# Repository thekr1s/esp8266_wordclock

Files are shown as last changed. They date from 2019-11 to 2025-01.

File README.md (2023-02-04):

# Get started on ubuntu 18.04 upto 20.04 (64 bits)
```
git clone https://github.com/thekr1s/esp8266_wordclock.git
cd esp8266_wordclock/esp-open-rtos
# NOTE Bearssl is outdated, and doesn't support CAfile, therefor disable check
git config --global http.sslverify false
git submodule update --init --recursive
cd ..
tar -xvf esp-open-sdk.tgz 
sudo apt-get install make gcc g++
sudo pip install esptool
. env.sh
cd wordclock
make
```

# Program ESP
## Windows
- Install ESP8266Flasher : https://github.com/nodemcu/nodemcu-flasher
- Install the driver for the USB2Sereial http://www.wch.cn/download/CH341SER_ZIP.html

Start the ESP8266Flasher.exe en vul het onderstaande in:

- esp8266_wordclock\esp-open-rtos\bootloader\firmware_prebuilt\rboot.bin            @ 0x00000
- esp8266_wordclock\esp-open-rtos\bootloader\firmware_prebuilt\blank_config.bin     @ 0x01000
- esp8266_wordclock\wordclock\firmware\ws2812_buffer.bin                            @ 0x02000

## Linux
After building the firmware with 'make' as discribed above, type the folliwing command:
```
make do_flash
```

# Setup Wordclock
- hierbenik: the request is build by: sprintf(buf, "GET %s HTTP/1.1\r\nHost: %s\r\nConnection:keep-alive\r\nAccept: */*\r\n\r\n", request, url);
- hierbenik request: "/get_with_age.php

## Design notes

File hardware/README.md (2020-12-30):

# Parts
## Electronics:
- NodeMcu Lolin V3 ESP32 [Link](https://www.ebay.com/itm/NodeMCU-V3-ESP8266-ESP-12-E-Lua-CH340-WiFI-WLan-IoT-Lolin-Mini-N3A2-V9T3/312753940110)
- Led strip: WS2812B [Link](https://www.ebay.com/itm/1-5m-WS2812B-RGB-Led-Strip-Light-30-60-144Leds-m-Individual-Addressable-IC-DC5V/401755047203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)
- LDR: 5MM GL5537 [Link](https://www.ebay.com/itm/20pcs-Photoresistor-5MM-GL5537-LDR-Photo-Resistors-Light-Dependent-Resistor/381374819080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)
- 100kOhm Resistor [link](https://www.ebay.com/itm/100PCS-1-4W-0-25W-Metal-Film-Resistor-1-Full-Range-of-Values-0-to-10M/252838503547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) 
- flat cable
- Power wire
- micro USB
- USB A
## Shop / Bouwmarkt:
- For frames clock:
    - Ikea RIBBA frame 23cm [link](https://www.ikea.com/nl/nl/p/ribba-fotolijst-zwart-40378401/)
    - Ikea RIBBA frame 50cm [link](https://www.ikea.com/nl/nl/p/ribba-fotolijst-zwart-00378436/)
- Multiplex timmerplaat gegrond 3 mm 122x61
- MDF 122x61cm 12/15mm
- Hoekprofiel aluminium 12x12/15x15 mm 2 meter
- Bison 2-componentenlijm kombi metaal 24 ml
- Plaatschroef 3x13 mm cilinderkop
## Special:
- letterplate
    - laser cutting: €50.0/€150.0
- led-divider cnc: (time)

# Electronic Wiring
- ESP(Rx) -> Led Strip (Data)
- ESP(GND) -> Led Strip (GND)
- ESP(VU) -> Led Strip (5v)
- LDR(1) -> ESP(GND)
- LDR(2) -> ESP(A0)
- ESP(A0) -> RESISTOR(100kOhm) -> ESP(3v)

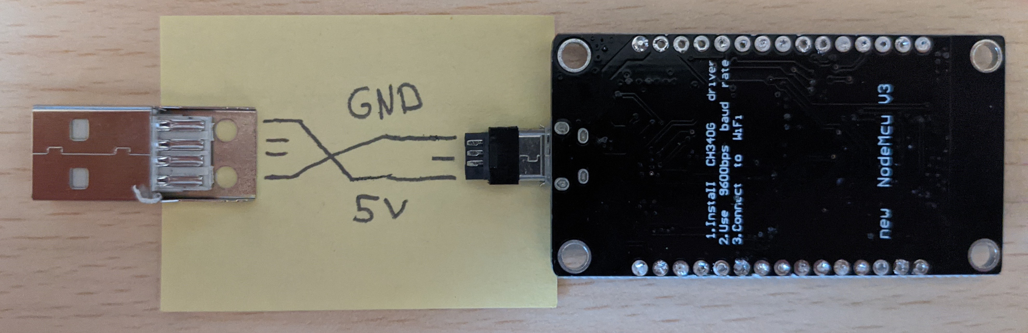
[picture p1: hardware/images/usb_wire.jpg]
- 

# Build Types
The wordclock can be created in 2 sizes because of the used led strip. Its 60 LED's per meter or 30 LED's per meter.
## Normal (Desk size)
- 60 Leds per meter
    - 11x11 letters => 121 LED's => (2.01m) => 3 meter ledstrip
- 12mm MDF plate 23*23 cm
- Hardboard 23*23 cm
### Frame (ikea RIBBA) 
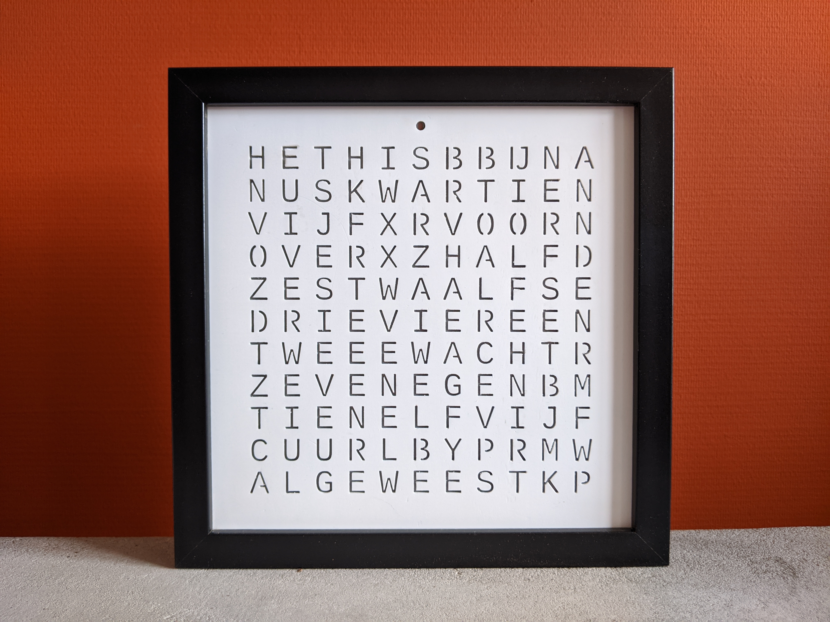
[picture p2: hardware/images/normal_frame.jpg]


### Frameless
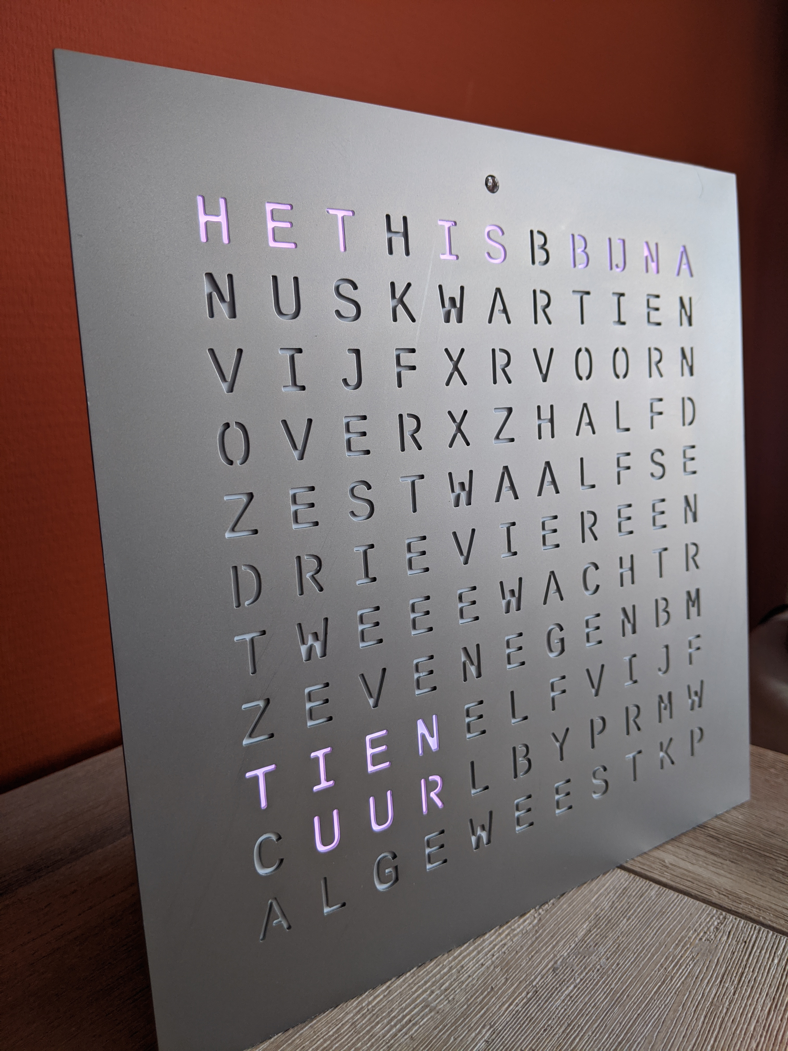
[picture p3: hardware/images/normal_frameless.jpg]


## Big clock (wall size)
The Big clock can be created with 11x11 letters or 13x13 letters
- 30 Leds per meter
    - 11x11 letters => 121 LED's => (4.04m) => 5 meter ledstrip
    - 13x13 letters => 169 LED's => (5.7m) => 6 meter ledstrip
- MDF plate 50*50 cm
- Hardboard 50*50 cm

### Frame 11x11 letters


### Frame 13x13 letters
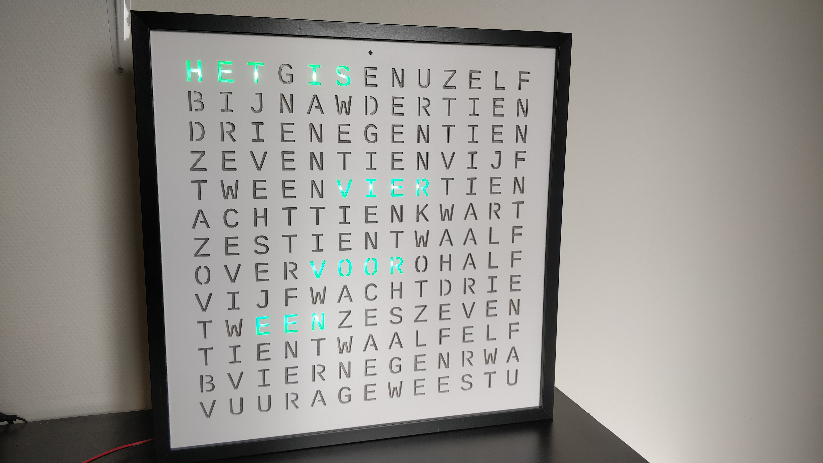
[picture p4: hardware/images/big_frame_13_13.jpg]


### Frameless 13x13 letters
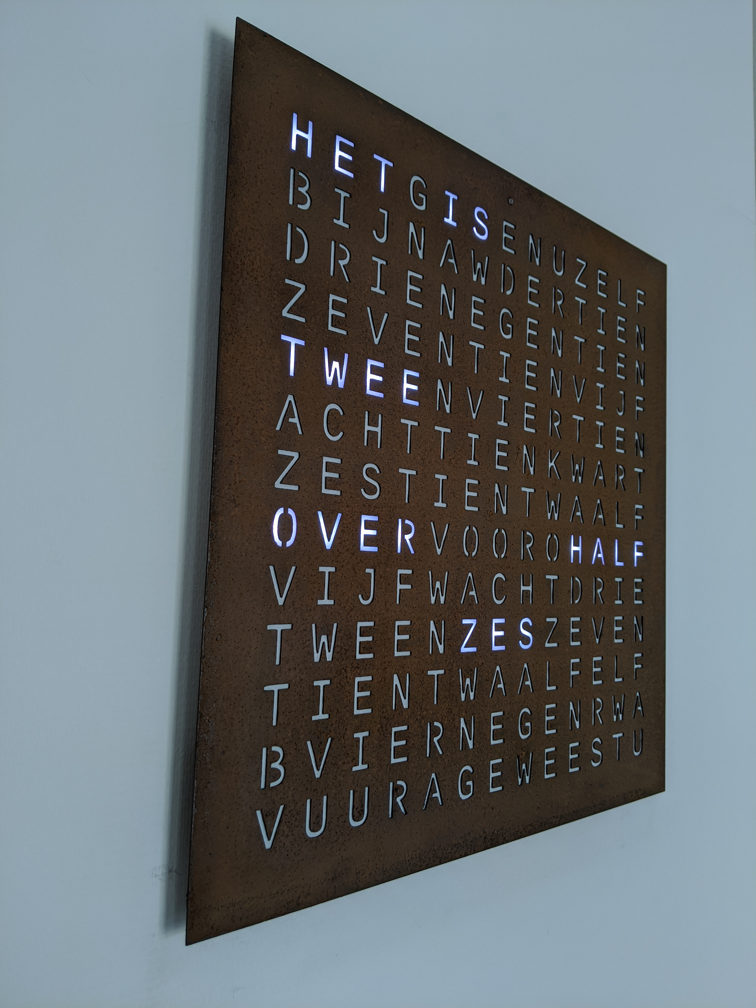
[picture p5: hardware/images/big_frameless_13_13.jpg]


# Assemble
The assembly can be divided into the following parts:
- led-panel
- light-divider
- letterplate
- Electronics
## light-divider
### CNC light-divider
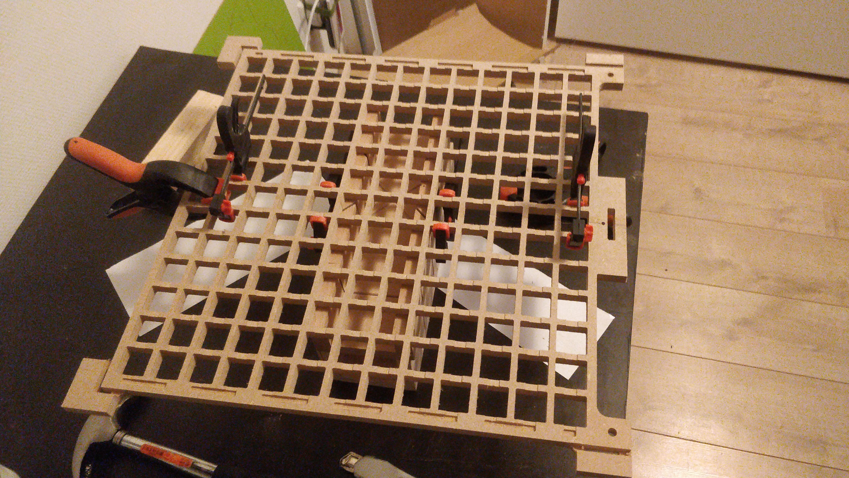
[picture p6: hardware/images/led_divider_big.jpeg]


### light-divider by hand
For the famed Clock the MDF plate need's to be 23x23 or 50x50 cm. For the frameless the MDF plate can be LxB 21x20 or 45,5x47 but start with 23x23 or 50x50.
The Normal clock can be made with 9mm or 12mm MDF plate.
The big clock can be made with 12mm or 15mm MDF plate.
- Determine the center of the plate by drawing 2 lines
- From the center draw a grid of lines
    - For the 60 led's per meter -> distance between lines is 1.6666 cm
    - For the 30 led's per meter -> distance between lines is 3.3333 cm
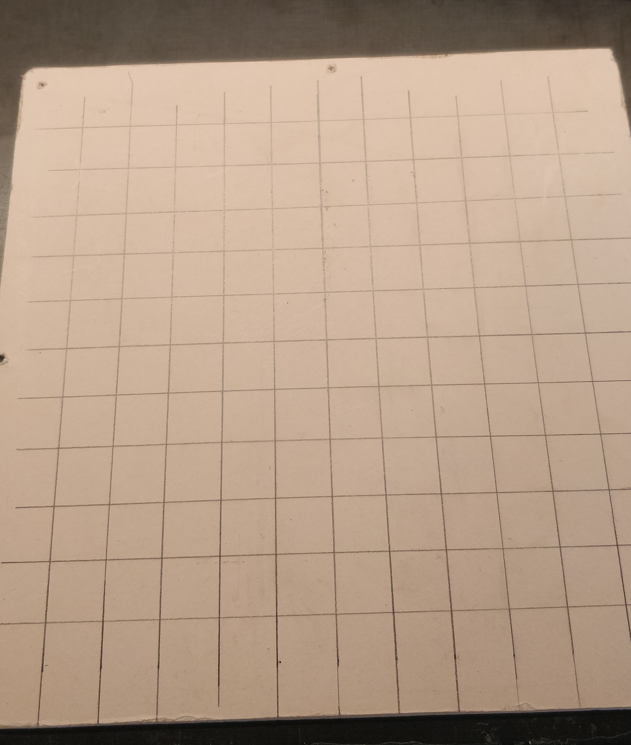
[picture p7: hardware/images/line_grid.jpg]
- 
- Drill a hole through each line crossing
    - Use a speed drill or a countersink bit
    - For the normal clock the hole is 12mm
    - For the big clock the hole is 30mm
- For the frameless clock the bottom, right and left side can be shorted so the letterplate will floating from the wall ~15mm(aluminium strip width) + 2mm spare
    - The top side is used to hang the clock
- The result should look like the cnc light-divider

## led-panel
- Place the led-panel under the light-divider.
- Trace the first, middle and last holes from the light-divider on the led panel
- Trace the outer line from the light-divider
    - in case of the frameless the top can be shorten 2 cm
- Cut peace’s from the ledstrip, (cut on the line that is drawn on the 3 copper paths)
    - For the 11x11 clock the ledstrip should be 11 leds long 
    - For the 13x13 clock the ledstrip should be 13 leds long 
- Place the led-strips with the led centred on the traces on the hardboard by following the this pattern:
    - Start upper left with Din and place it to the upper Right side end with Dout
    - The second row start with Dout on the left side and ends with Din
    - continue this zigzag pattern until all rows are done
- Use a Flat cable to connect the ledstrips from Dout to Din.
    - Cut flat cable, strip and tin both ends, cut the both ends so they are separated from each other
    - pre-solder both ends of the ledstrip
    - Start upper right with Dout solder all 3 pins(GND, Dout, 5V) Fold the flat cable 90 degrees down, fold it 90 degrees towards Din Solder again
- drill a hole next to the first led, and next to the last led
- Connect power supply from the first led to the last led with the red/black wire
- Connect the powers supply and the Din with the ESP (see Electronic Wiring)
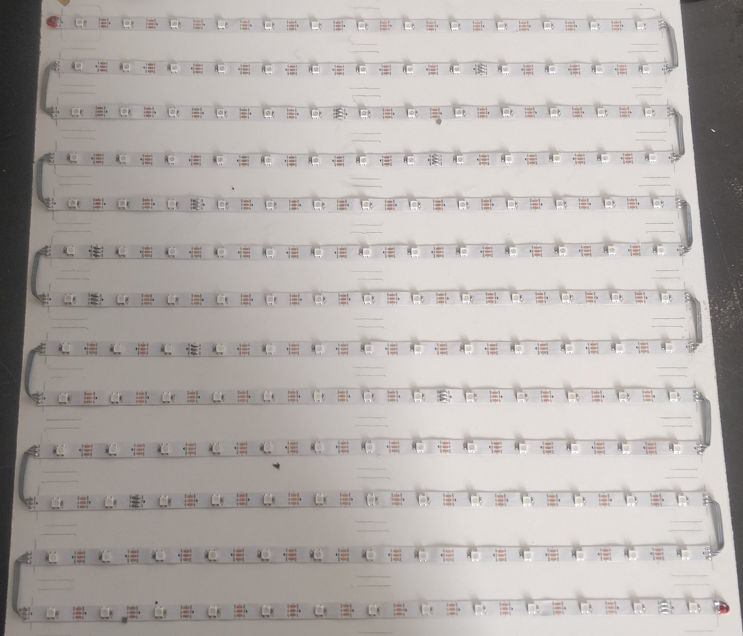
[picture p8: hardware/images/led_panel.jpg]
- 
- You should be able to test the LED panel by connection the ESP to its power supply

## Connect the led-panel with the light-divider
- Place the light-divider on the led-panel and make sure all leds are centred
- Drill (1.5mm) hole through both panels. These hols can later be used to connect both panels
- Flip it and screw both panels to each other.
- Frameless ESP placement
    - Big clock place the ESP in the upper right corner (hot glue)
    - Normal clock the ESP will be screwed to the back
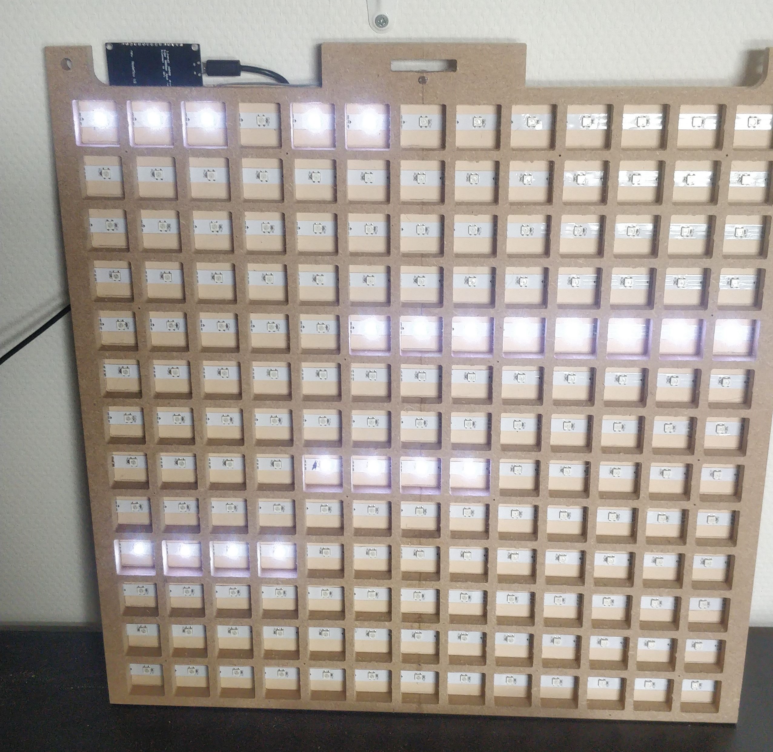
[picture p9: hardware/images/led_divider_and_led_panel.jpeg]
- 

## Diffuser (to be improved)
- place the paper over the light-divider and cut it on size
- make sure its stays in place with tape

## Letterplate
### frame
- Connect the LDR and the resistor (see Electronic Wiring)
- fix the ESP with a screw to the back of the led-panel
- Place the letterplate and the light divider in the frame
- place some foam in the back so all is pushed forwarded
- Close the frame
### frameless
- Center the light-divider on the letterplate and drill the LDR hole
- Draw the outer line from the light-divider on theletterplates back
- Cut the aluminium strip so it fits nicely around the light-divider (left, right and bottom)
- Make both the letterplate and the aluminium strip rough with sanding paper
- drill 3 holes in all aluminium strips (used for connecting the letterplate to the light-divider)
- glue the aluminium strip on the letterplate (use glue clamps) wait 24 hours
- screw the letterplate to the light-divider
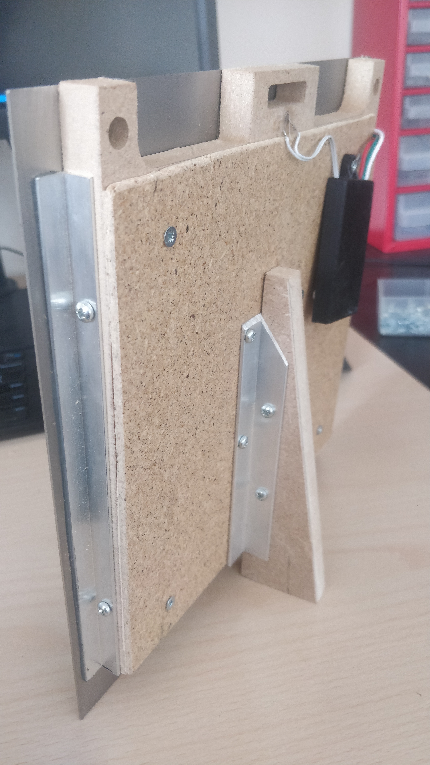
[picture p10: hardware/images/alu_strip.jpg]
- 

# Hardware Drawings
## letterplate
- I Have created a FreeCAD pyhton macro for generating a Letterplate, ..\hardware\lettering_plates\FreeCAD_drawings\freecad_macro
- The letterplate is parametric so can be used for 11*11 of 13*13
- After the generation is done, export the part as .STEP (the DXF generator from freecad is not smooth)
- FreeCAD export DXF WORKS (0.18.4):
    - Edit -> Preference -> Inport-Export -> DXF
    - Max Spline Segment to 0,1 or 0,01 mm (NOTE use , instead of .)
    - Select all elements
    - File -> Export -> Autodesk DXF 2d
- Import the .STEP file into Fusion for creating the DXF file of gcode
- G-code
    - Create A body by setting the Hight
    - Switch to manufacture
    - start creating the Gcode
- DXF:
    - Create a sketch on the Top view
    - Menu -> Create -> Project / include -> include 3D Geometry
    - Select the Body from the letterplate
    - Save Sketch -> right klik the Sketch and save as DXF
## ledschotten
- The LDR for the 11*11 clock is 214.444 mm from the bottom (This information is printed by FreeCAD)
- The LDR for the 13*13 clock is 477.778 mm from the bottom
- The LEDschotten is completely drawn in Fusion360, and is partly parametric.

# Tips & tricks:
- The MDF plate can also be replaced by "Foamed pvc"

# Note:
The NodeMcu Lolin V3 is needed because the Lolin has a 3v reference voltage for its adc that is used for the LDR all other NodeMC have 1v reference voltage

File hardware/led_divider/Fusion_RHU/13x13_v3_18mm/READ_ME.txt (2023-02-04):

#Init homing 
G92 x0 y0 z0
f10000
x5 y30
G92 x0 y0 z0
#plase the inital tool 2mm?
M6

#Jog to Z0 (top of wood)
G92 Z0
Z20

The flip pins fixure is:
240*550mm
Starts on X5 Y30

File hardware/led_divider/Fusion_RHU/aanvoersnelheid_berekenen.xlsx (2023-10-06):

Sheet: Blad1
Aanvoersnelheid = (aanvoer x 1000) : (toerental x aantal tanden)

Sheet: Materiaal Fz
https://www.stepcraft-systems.com/en/services/milling-parameters
 | End Mill Diamater
ø Cutting Speed | ø 1 mm | ø 2 mm | ø 3 mm | ø 4 mm | ø 5 mm | ø 6 mm | ø 8 mm | ø 10 mm | ø 12 mm
m/min.* | Feed Rate in mm / Tooth / Revolution
Cast Aluminum > 6 % Si | 200 | 0.01 | 0.01 | 0.01 | 0.015 | 0.015 | 0.025 | 0.03 | 0.038 | 0.05
Wrought Aluminum Alloy | 500 | 0.01 | 0.02 | 0.025 | 0.05 | 0.05 | 0.05 | 0.064 | 0.08 | 0.1
Soft Plastic | 600 | 0.025 | 0.03 | 0.035 | 0.045 | 0.065 | 0.09 | 0.1 | 0.2 | 0.3
Hard Plastic | 550 | 0.015 | 0.02 | 0.025 | 0.05 | 0.06 | 0.08 | 0.089 | 0.1 | 0.15
Hard Wood | 450 | 0.02 | 0.025 | 0.03 | 0.055 | 0.065 | 0.085 | 0.095 | 0.095 | 0.155
Soft Wood | 500 | 0.025 | 0.03 | 0.035 | 0.06 | 0.07 | 0.09 | 0.1 | 0.11 | 0.16
MDF | 450 | 0.05 | 0.07 | 0.1 | 0.15 | 0.2 | 0.3 | 0.4 | 0.5 | 0.6
Brass, Copper, Bronze | 365 | 0.015 | 0.02 | 0.025 | 0.025 | 0.03 | 0.05 | 0.056 | 0.065 | 0.08
Steel | 75 | 0.01 | 0.01 | 0.012 | 0.025 | 0.03 | 0.038 | 0.045 | 0.05 | 0.08

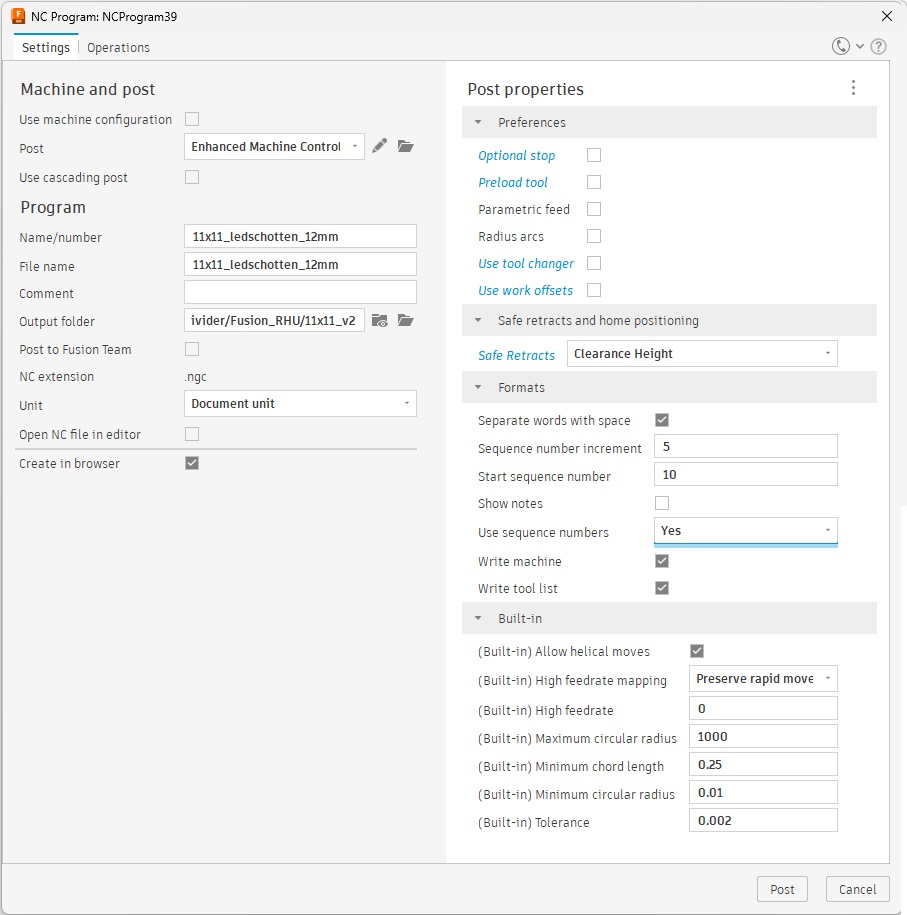
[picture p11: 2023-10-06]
hardware/led_divider/Fusion_RHU/FUSION_SETTINGS_POST_PROCESS.jpg

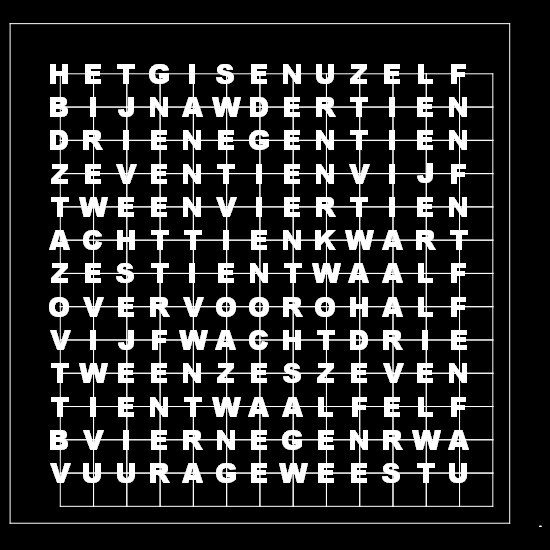
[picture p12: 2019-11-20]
hardware/lettering_plates/QCAD_letterplaat/WOORDCLOCK_2.bmp

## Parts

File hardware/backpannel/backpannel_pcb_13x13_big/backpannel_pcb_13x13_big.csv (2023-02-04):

Source: | Y:\home\rutger\proj\esp8266_wordclock\hardware\backpannel\backpannel_pcb_13x13_big\backpannel_pcb_13x13_big.kicad_sch
Date: | 29/12/2022 17:19:29
Tool: | Eeschema (6.0.0)
Generator: | C:\Program Files\KiCad\6.0\bin\scripting\plugins/bom_csv_grouped_by_value.py
Component Count: | 32
Individual Components:
Item | Qty | Reference(s) | Value | LibPart | Footprint | Datasheet
 |  | C1 | 10uF | Device:C | Capacitor_SMD:C_0805_2012Metric_Pad1.18x1.45mm_HandSolder | ~
 |  | C2 | 10uF | Device:CP | Capacitor_SMD:CP_Elec_6.3x5.4
 |  | C3 | 10uF | Device:C | Capacitor_SMD:C_0805_2012Metric_Pad1.18x1.45mm_HandSolder | ~
 |  | D1 | D_Schottky | Device:D_Schottky | Diode_SMD:D_0805_2012Metric_Pad1.15x1.40mm_HandSolder | ~
 |  | J1 | Conn_02x03 | Connector_Generic:Conn_02x03_Odd_Even | Connector_PinHeader_2.54mm:PinHeader_2x03_P2.54mm_Vertical | ~
 |  | J2 | Conn_01x02_Female | Connector:Conn_01x03_Female | Connector_BarrelJack:BarrelJack_CLIFF_FC681465S_SMT_Horizontal | ~
 |  | JP1 | ledstrip | Jumper:SolderJumper_2_Open | Jumper:SolderJumper-2_P1.3mm_Open_RoundedPad1.0x1.5mm | ~
 |  | R1 | 100k | Device:R | Resistor_SMD:R_0805_2012Metric_Pad1.20x1.40mm_HandSolder | ~
 |  | R2 | LDR | Sensor_Optical:LDR03 | OptoDevice:R_LDR_5.1x4.3mm_P3.4mm_Vertical | http://www.elektronica-componenten.nl/WebRoot/StoreNL/Shops/61422969/54F1/BA0C/C664/31B9/2173/C0A8/2AB9/2AEF/LDR03IMP.pdf
 |  | R3 | 100k | Device:R | Resistor_SMD:R_0805_2012Metric_Pad1.20x1.40mm_HandSolder | ~
 |  | R4 | 220k | Device:R | Resistor_SMD:R_0805_2012Metric_Pad1.20x1.40mm_HandSolder | ~
 |  | R5 | 12k | Device:R | Resistor_SMD:R_0805_2012Metric_Pad1.20x1.40mm_HandSolder | ~
 |  | R6 | 12k | Device:R | Resistor_SMD:R_0805_2012Metric_Pad1.20x1.40mm_HandSolder | ~
 |  | R7 | 12k | Device:R | Resistor_SMD:R_0805_2012Metric_Pad1.20x1.40mm_HandSolder | ~
 |  | R8 | 12k | Device:R | Resistor_SMD:R_0805_2012Metric_Pad1.20x1.40mm_HandSolder | ~
 |  | R9 | 12k | Device:R | Resistor_SMD:R_0805_2012Metric_Pad1.20x1.40mm_HandSolder | ~
 |  | R10 | 330 | Device:R | Resistor_SMD:R_0805_2012Metric_Pad1.20x1.40mm_HandSolder | ~
 |  | S1 | WS2812_ledstrip | woordklok_symbol:WS2812_ledstrip | woordklok_footprint:WS2812_ledstrip_30leds_meter
 |  | S2 | WS2812_ledstrip | woordklok_symbol:WS2812_ledstrip | woordklok_footprint:WS2812_ledstrip_30leds_meter
 |  | S3 | WS2812_ledstrip | woordklok_symbol:WS2812_ledstrip | woordklok_footprint:WS2812_ledstrip_30leds_meter
 |  | S4 | WS2812_ledstrip | woordklok_symbol:WS2812_ledstrip | woordklok_footprint:WS2812_ledstrip_30leds_meter
 |  | S5 | WS2812_ledstrip | woordklok_symbol:WS2812_ledstrip | woordklok_footprint:WS2812_ledstrip_30leds_meter
 |  | S6 | WS2812_ledstrip | woordklok_symbol:WS2812_ledstrip | woordklok_footprint:WS2812_ledstrip_30leds_meter
 |  | S7 | WS2812_ledstrip | woordklok_symbol:WS2812_ledstrip | woordklok_footprint:WS2812_ledstrip_30leds_meter
 |  | S8 | WS2812_ledstrip | woordklok_symbol:WS2812_ledstrip | woordklok_footprint:WS2812_ledstrip_30leds_meter
 |  | S9 | WS2812_ledstrip | woordklok_symbol:WS2812_ledstrip | woordklok_footprint:WS2812_ledstrip_30leds_meter
 |  | S10 | WS2812_ledstrip | woordklok_symbol:WS2812_ledstrip | woordklok_footprint:WS2812_ledstrip_30leds_meter
 |  | S11 | WS2812_ledstrip | woordklok_symbol:WS2812_ledstrip | woordklok_footprint:WS2812_ledstrip_30leds_meter
 |  | S12 | WS2812_ledstrip | woordklok_symbol:WS2812_ledstrip | woordklok_footprint:WS2812_ledstrip_30leds_meter
 |  | S13 | WS2812_ledstrip | woordklok_symbol:WS2812_ledstrip | woordklok_footprint:WS2812_ledstrip_30leds_meter
 |  | U1 | AMS1117-3.3 | Regulator_Linear:AMS1117-3.3 | Package_TO_SOT_SMD:SOT-223-3_TabPin2 | http://www.advanced-monolithic.com/pdf/ds1117.pdf
 |  | U2 | ESP-12E | RF_Module:ESP-12E | RF_Module:ESP-12E | http://wiki.ai-thinker.com/_media/esp8266/esp8266_series_modules_user_manual_v1.1.pdf
Collated Components:
Item | Qty | Reference(s) | Value | LibPart | Footprint | Datasheet
1 | 2 | C1, C3 | 10uF | Device:C | Capacitor_SMD:C_0805_2012Metric_Pad1.18x1.45mm_HandSolder | ~
2 | 1 | C2 | 10uF | Device:CP | Capacitor_SMD:CP_Elec_6.3x5.4
3 | 1 | D1 | D_Schottky | Device:D_Schottky | Diode_SMD:D_0805_2012Metric_Pad1.15x1.40mm_HandSolder | ~
4 | 1 | J1 | Conn_02x03 | Connector_Generic:Conn_02x03_Odd_Even | Connector_PinHeader_2.54mm:PinHeader_2x03_P2.54mm_Vertical | ~
5 | 1 | J2 | Conn_01x02_Female | Connector:Conn_01x03_Female | Connector_BarrelJack:BarrelJack_CLIFF_FC681465S_SMT_Horizontal | ~
6 | 1 | JP1 | ledstrip | Jumper:SolderJumper_2_Open | Jumper:SolderJumper-2_P1.3mm_Open_RoundedPad1.0x1.5mm | ~
7 | 2 | R1, R3 | 100k | Device:R | Resistor_SMD:R_0805_2012Metric_Pad1.20x1.40mm_HandSolder | ~
8 | 1 | R2 | LDR | Sensor_Optical:LDR03 | OptoDevice:R_LDR_5.1x4.3mm_P3.4mm_Vertical | http://www.elektronica-componenten.nl/WebRoot/StoreNL/Shops/61422969/54F1/BA0C/C664/31B9/2173/C0A8/2AB9/2AEF/LDR03IMP.pdf
9 | 1 | R4 | 220k | Device:R | Resistor_SMD:R_0805_2012Metric_Pad1.20x1.40mm_HandSolder | ~
10 | 5 | R5, R6, R7, R8, R9 | 12k | Device:R | Resistor_SMD:R_0805_2012Metric_Pad1.20x1.40mm_HandSolder | ~
11 | 1 | R10 | 330 | Device:R | Resistor_SMD:R_0805_2012Metric_Pad1.20x1.40mm_HandSolder | ~
12 | 13 | S1, S2, S3, S4, S5, S6, S7, S8, S9, S10, S11, S12, S13 | WS2812_ledstrip | woordklok_symbol:WS2812_ledstrip | woordklok_footprint:WS2812_ledstrip_30leds_meter
13 | 1 | U1 | AMS1117-3.3 | Regulator_Linear:AMS1117-3.3 | Package_TO_SOT_SMD:SOT-223-3_TabPin2 | http://www.advanced-monolithic.com/pdf/ds1117.pdf
14 | 1 | U2 | ESP-12E | RF_Module:ESP-12E | RF_Module:ESP-12E | http://wiki.ai-thinker.com/_media/esp8266/esp8266_series_modules_user_manual_v1.1.pdf

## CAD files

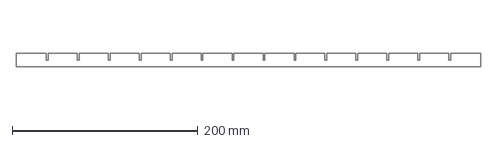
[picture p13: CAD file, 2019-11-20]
hardware/__attic/shotten/schotjes_layout_15mm.dxf
500.0 x 15.0 mm

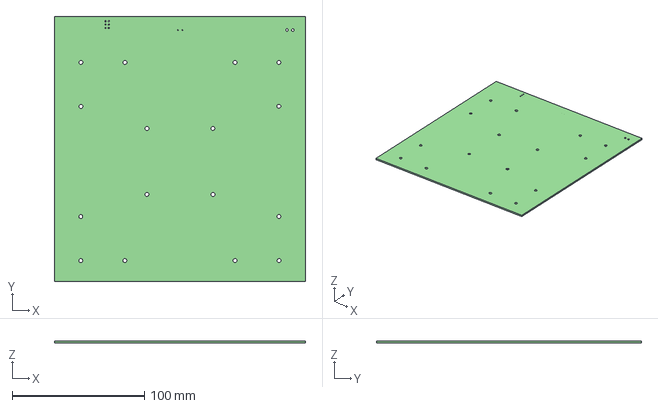
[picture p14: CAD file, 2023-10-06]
hardware/backpannel/backpannel_pcb_11x11_small/backpannel_pcb_11x11_small.step
190.0 x 200.6 x 1.60 mm

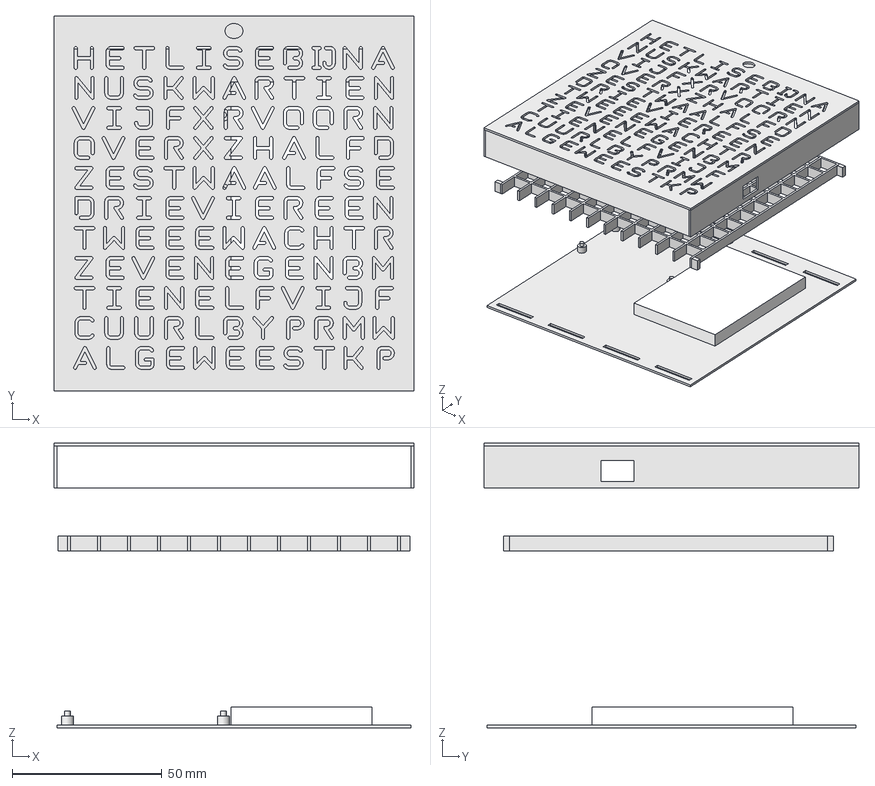
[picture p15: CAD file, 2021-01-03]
hardware/housing/120x120/housing.FCStd
120.0 x 125.0 x 95.0 mm
Letterplate
backsink

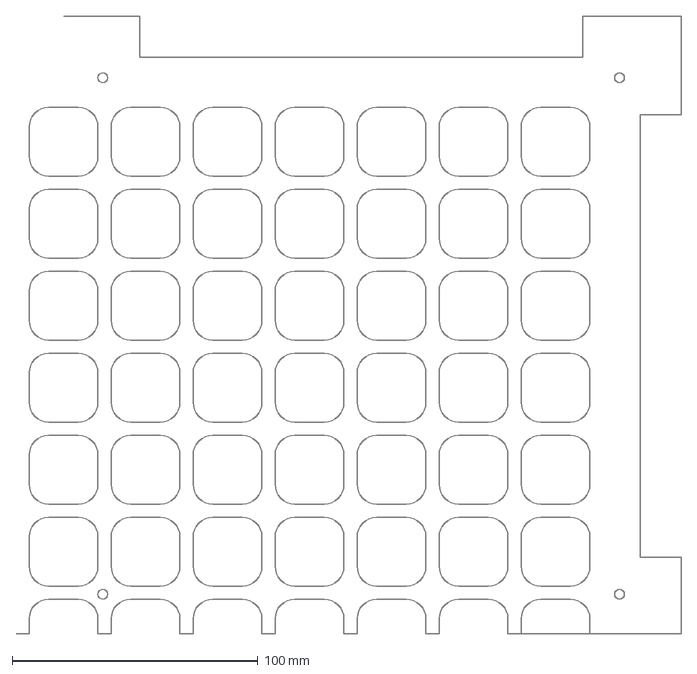
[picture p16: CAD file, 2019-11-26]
hardware/led_divider/cambam_RWA/gatenboard_groot_13x13_kwart.dxf
270.3 x 251.0 mm

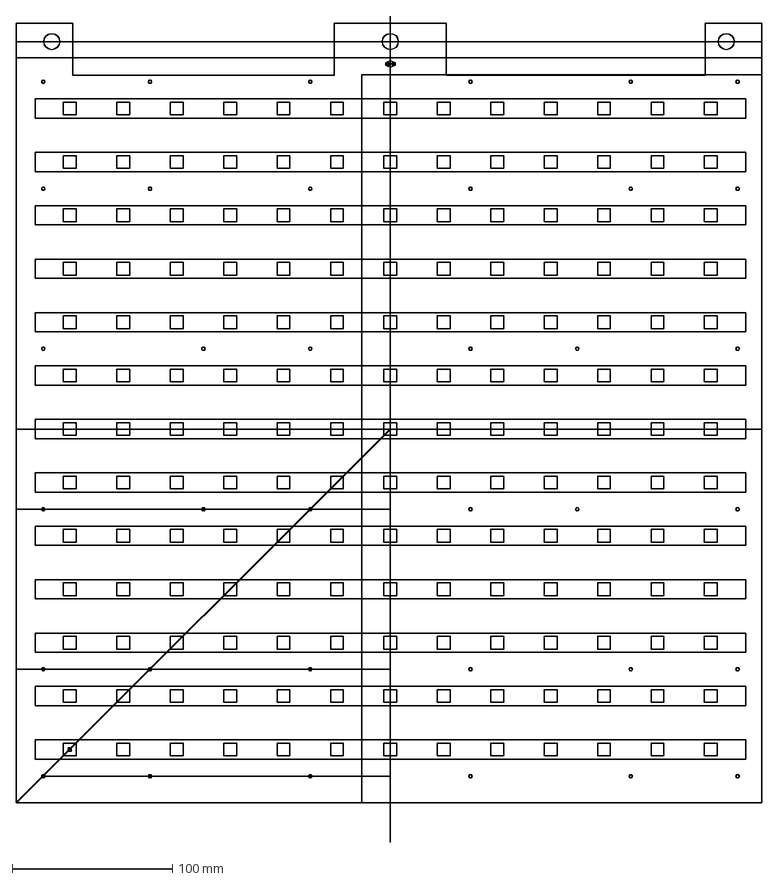
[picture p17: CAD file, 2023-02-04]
hardware/led_divider/Fusion_RHU/ledschotten_13_13_V2.dxf
465.0 x 515.4 mm

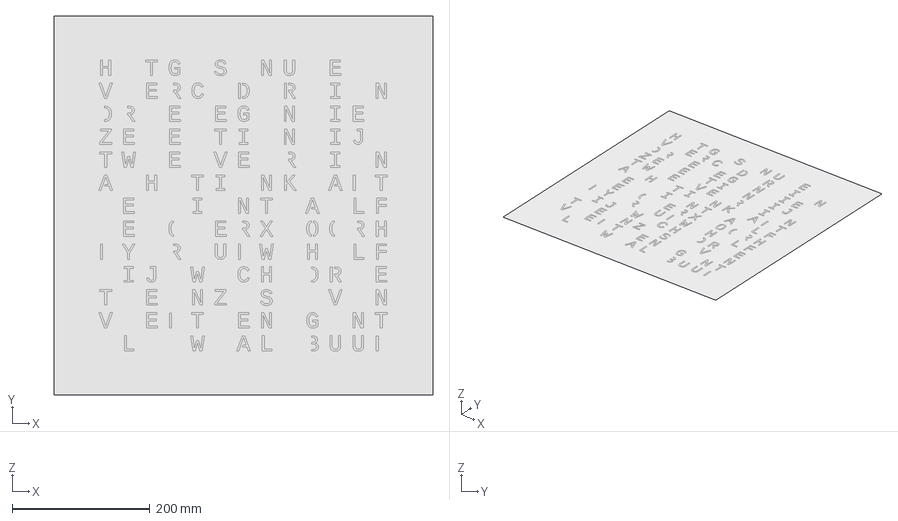
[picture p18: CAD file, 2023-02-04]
hardware/lettering_plates/FreeCAD_drawings/letterplate_13_13_V2_freecad.step
550.0 x 550.0 x 0 mm
Circle
ShapeString
ShapeString001
ShapeString002
ShapeString003
ShapeString004
ShapeString005
ShapeString006
ShapeString007
ShapeString008
ShapeString009
ShapeString010
ShapeString011
ShapeString012
ShapeString013
ShapeString014
ShapeString015
ShapeString016
ShapeString017
ShapeString018
ShapeString019
ShapeString020
ShapeString021
ShapeString022
ShapeString023
ShapeString024
ShapeString025
ShapeString026
ShapeString027
ShapeString028
ShapeString029
ShapeString030
ShapeString031
ShapeString032
ShapeString033
ShapeString034
ShapeString035
ShapeString036
ShapeString037
ShapeString038
ShapeString039
ShapeString040
ShapeString041
ShapeString042
ShapeString043
ShapeString044
ShapeString045
ShapeString046
ShapeString047
ShapeString048
ShapeString049
ShapeString050
ShapeString051
ShapeString052
ShapeString053
ShapeString054
ShapeString055
ShapeString056
ShapeString057
ShapeString058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

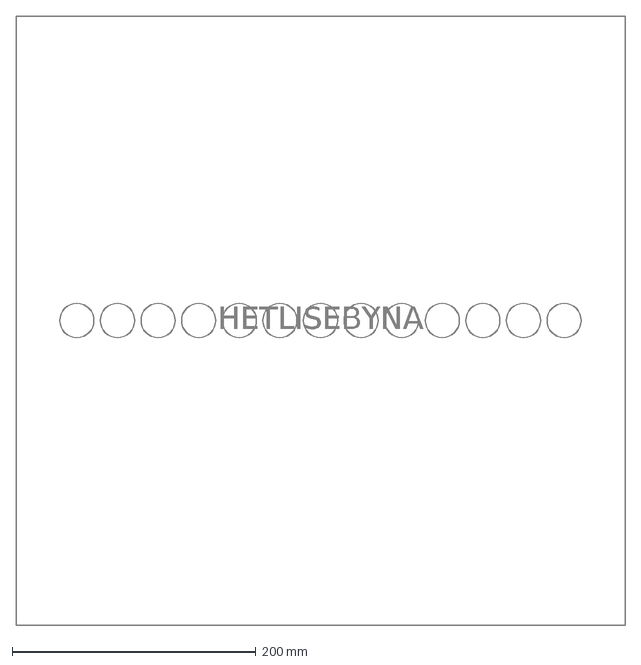
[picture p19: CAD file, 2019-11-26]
hardware/lettering_plates/letterplaat_rwa/letterplaat_groot.dxf
HETLISEBYNA

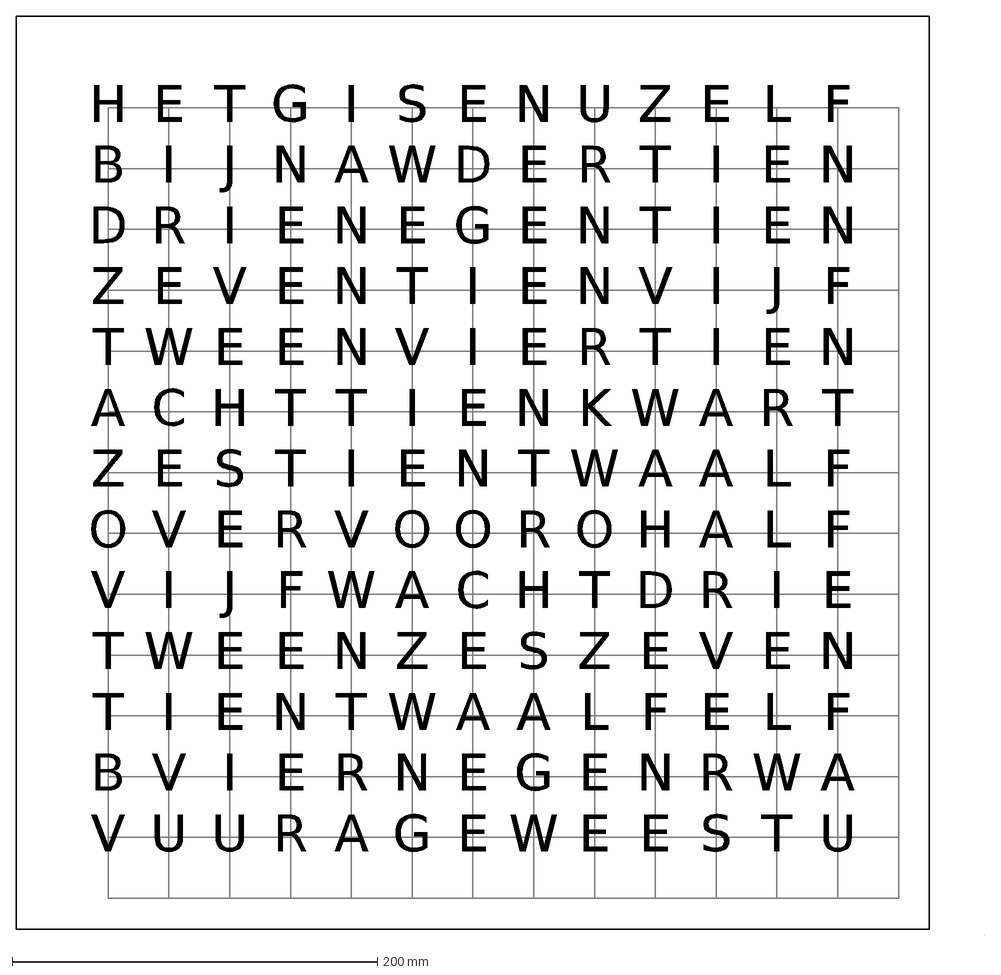
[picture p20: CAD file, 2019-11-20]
hardware/lettering_plates/QCAD_letterplaat/WOORDCLOCK_2.dxf
H
E
T
G
I
S
N
U
Z
L
F
W
D
A
R
B
J
V
K
C
O

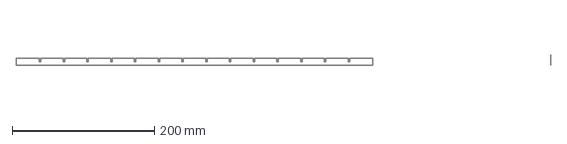
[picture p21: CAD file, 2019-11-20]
hardware/__attic/shotten/schotjes_layout.dxf
750.0 x 15.0 mm

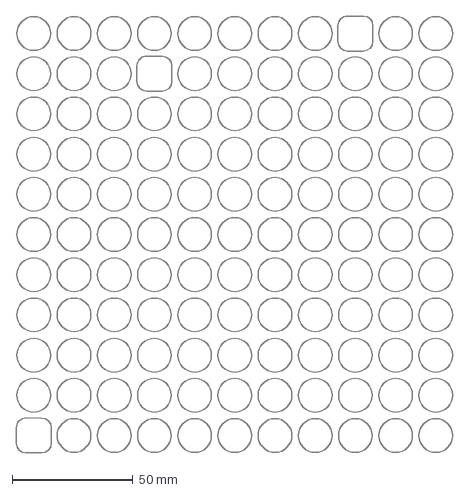
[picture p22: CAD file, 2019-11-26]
hardware/led_divider/cambam_RWA/gatenboard.dxf
180.9 x 181.2 mm

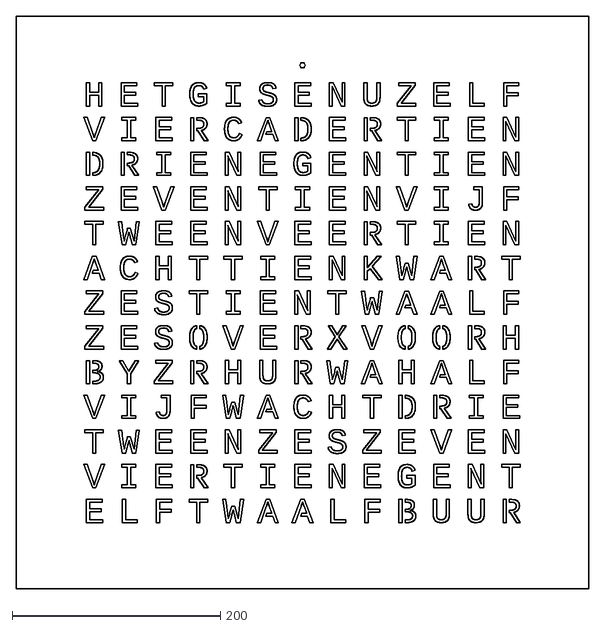
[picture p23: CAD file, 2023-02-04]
hardware/lettering_plates/FreeCAD_drawings/letterplate_13_13_V2_Qcad.dxf
550.0 x 550.0

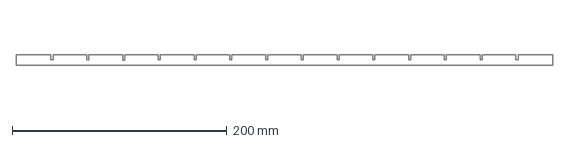
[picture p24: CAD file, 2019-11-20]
hardware/__attic/shotten/schotjes_layout_zonderMaten.dxf
500.0 x 10.0 mm

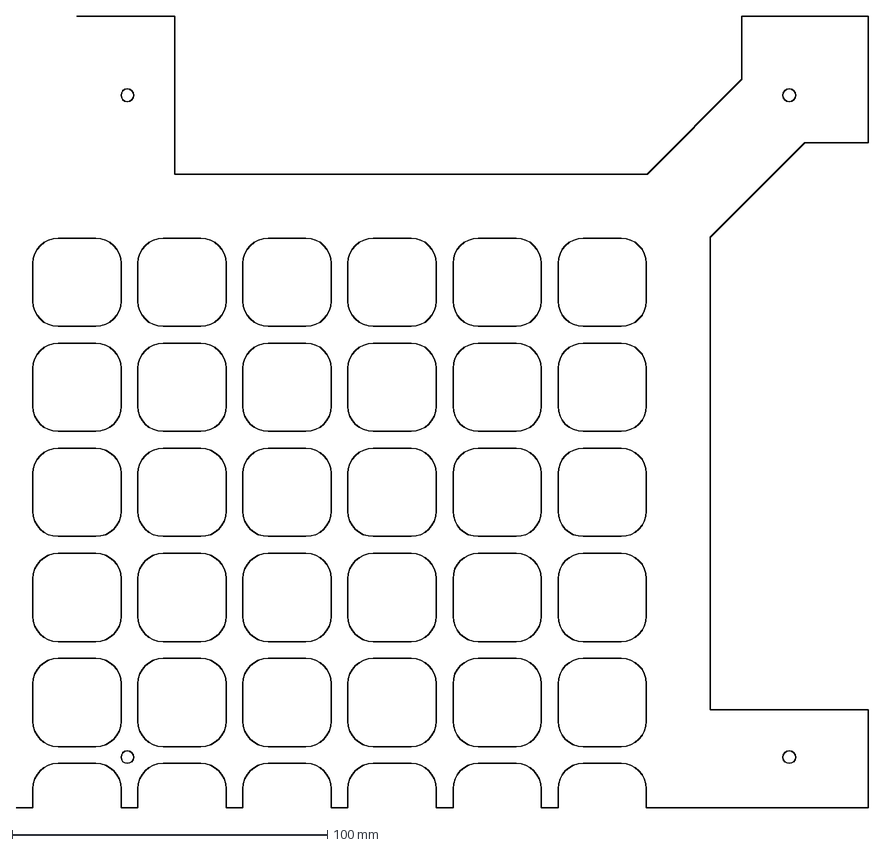
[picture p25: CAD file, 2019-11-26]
hardware/led_divider/cambam_RWA/gatenboard_groot_kwart.dxf
270.3 x 251.0 mm

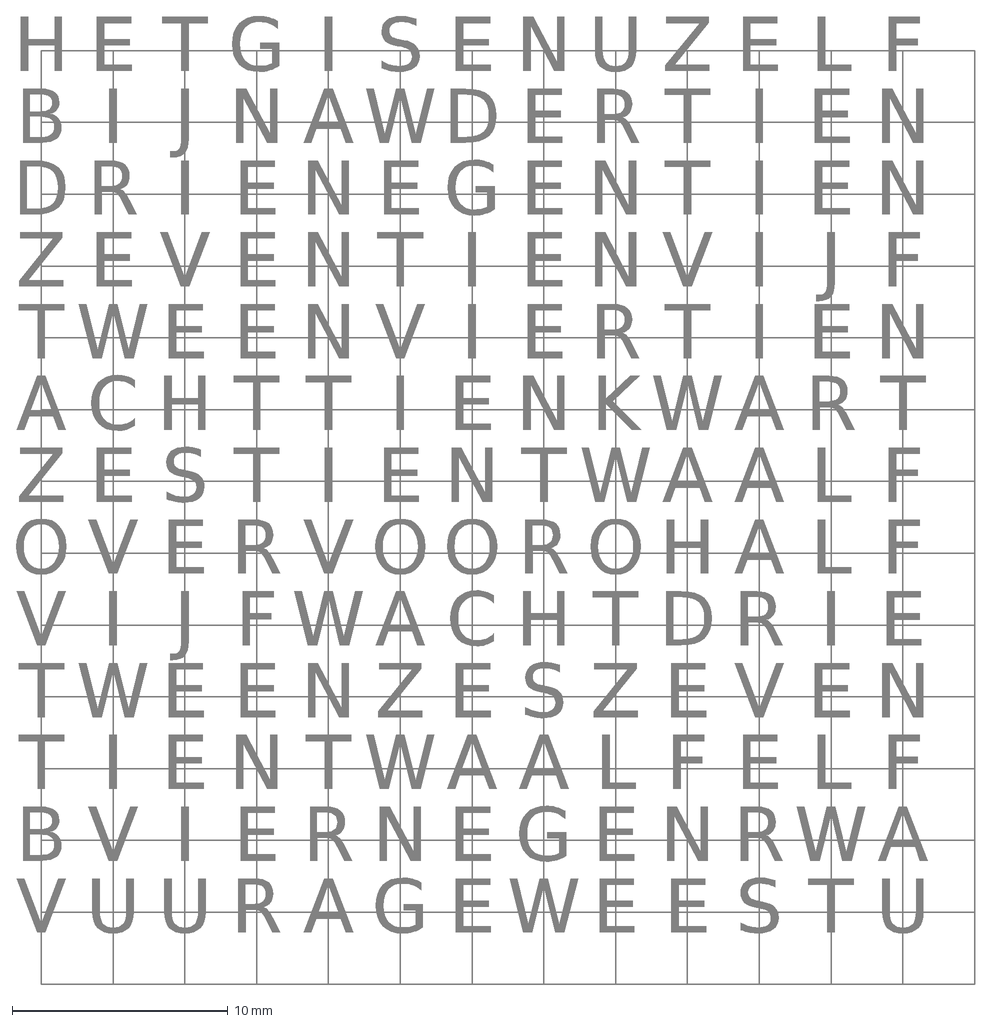
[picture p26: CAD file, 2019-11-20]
hardware/lettering_plates/QCAD_letterplaat/WOORDCLOCK.dxf
H
E
T
G
I
S
N
U
Z
L
F
W
D
A
R
B
J
V
K
C
O

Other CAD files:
hardware/lettering_plates/QCAD_letterplaat/WOORDCLOCK_3.dxf
hardware/led_divider/cambam_RWA/gatenboard_groot_13x13_half.dxf
hardware/lettering_plates/FreeCAD_drawings/letterplate_11_11_freecad.dxf
hardware/lettering_plates/QCAD_letterplaat/WOORDCLOCK_1.dxf
hardware/led_divider/Fusion_RHU/old/ledschotten_frameless_11_11 v29.stl
hardware/led_divider/Fusion_RHU/old/ledschotten_frameless_13_13 v14.stl
hardware/led_divider/Fusion_RHU/old/ledschotten_frameless_13_13 v16.stl
hardware/led_divider/Fusion_RHU/old/ledschotten_ikea_11_11 v9.dxf
hardware/led_divider/Fusion_RHU/old/ledschotten_ikea_11_11 v9.stl
hardware/led_divider/Fusion_RHU/old/ledschotten_ikea_13_13 v9.stl
hardware/lettering_plates/FreeCAD_drawings/letterplate_11_11.FCStd
hardware/lettering_plates/FreeCAD_drawings/letterplate_11_11_fusion360_v2.dxf
hardware/lettering_plates/FreeCAD_drawings/letterplate_13_13.FCStd
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

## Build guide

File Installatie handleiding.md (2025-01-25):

# Installatie handleiding
Deze handleiding zal stapsgewijs uitleggen hoe u de klok kunt installeren en gebruiken. Het laatste hoofdstuk zal veel gestelde vragen beantwoorden.
## Installatie 
De klok haalt zijn tijd op vanaf het internet, Dit kan de klok alleen doen zodra de klok verbind met uw WiFi thuis. Nadat de klok met uw WiFi is verbonden zal de klok altijd de goede tijd weergeven.
### Stap 1:
- Sluit de USB aan op een USB adapter van minimaal 1A, 
- Sluit de andere kant aan op de controller van de klok

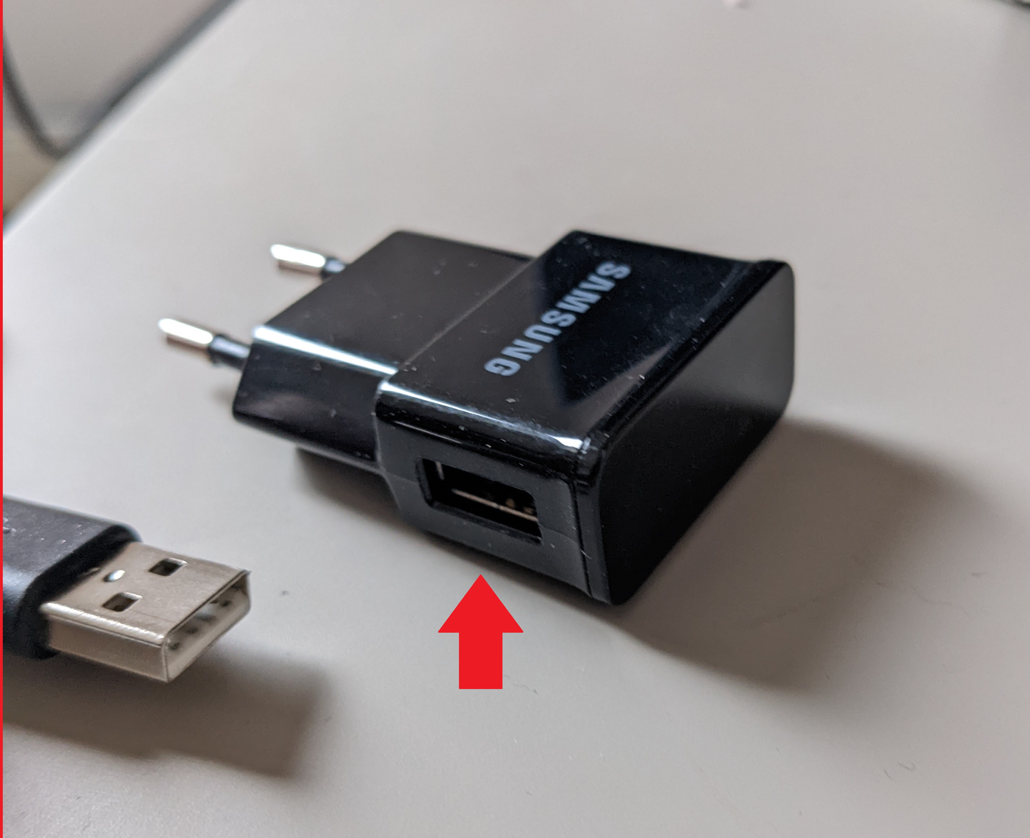
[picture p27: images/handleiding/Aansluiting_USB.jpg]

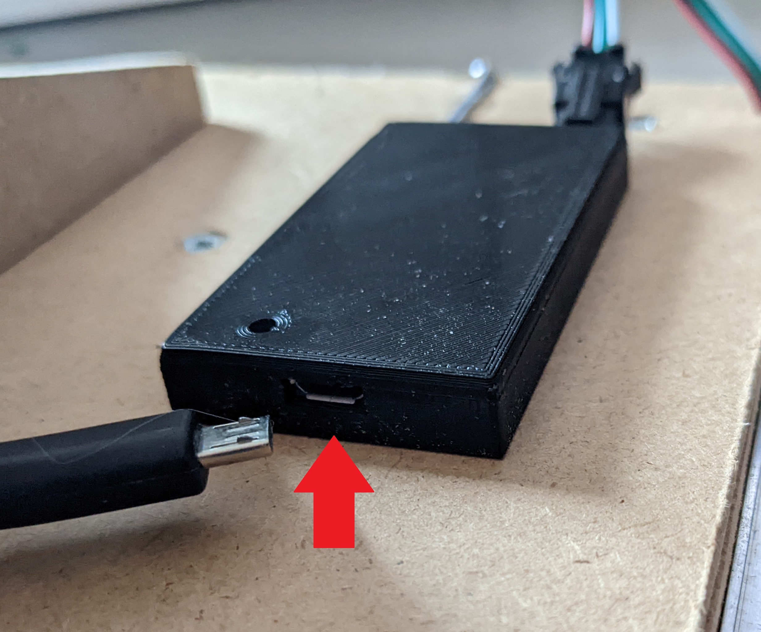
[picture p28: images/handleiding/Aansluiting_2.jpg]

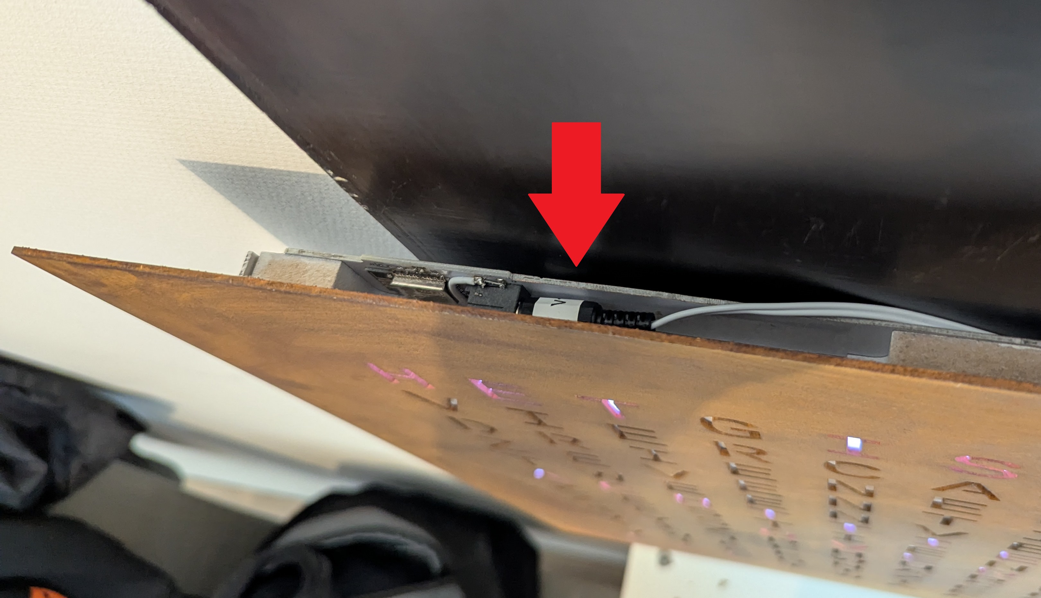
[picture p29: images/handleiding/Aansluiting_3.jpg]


- Uw klok zal opstarten en de onderstaande tekst zal over het scherm scrollen\
 `No WiFi Connect to woordklok WiFi and sign in`

### Stap 2 
- Open op uw telefoon/Laptop/tablet de WiFi instellingen
- Zoek naar de Wifi met de naam `woordklokxxxxxx` (de x maakt uw klok uniek) \
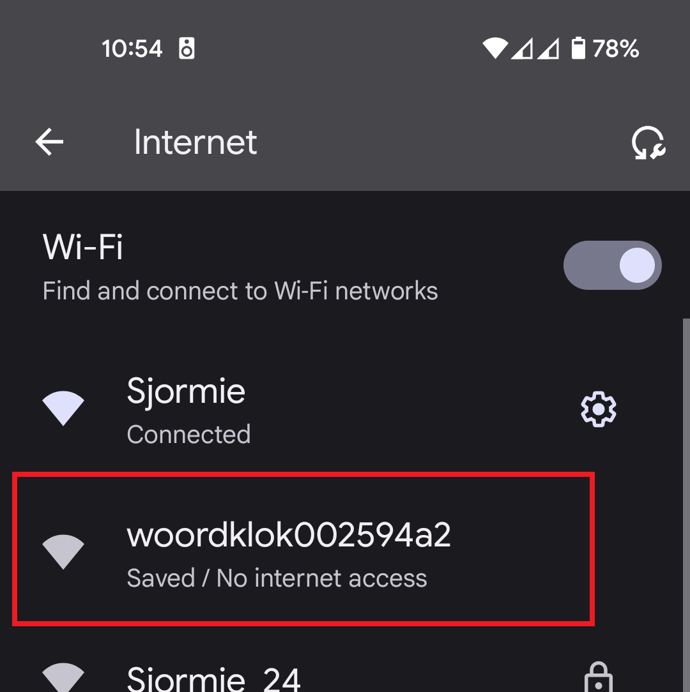
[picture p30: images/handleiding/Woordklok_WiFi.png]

- Verbind met de `woordklok` WiFi
- Klik op de Pop-up om in te loggen(de meeste telefoons doen dit automatisch):\
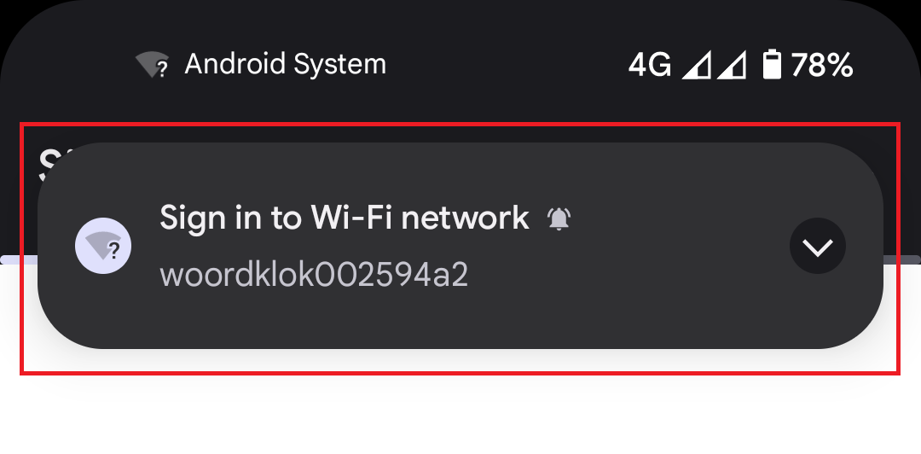
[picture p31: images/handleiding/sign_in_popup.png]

- Als alles goed is gegaan ziet u nu deze pagina: \
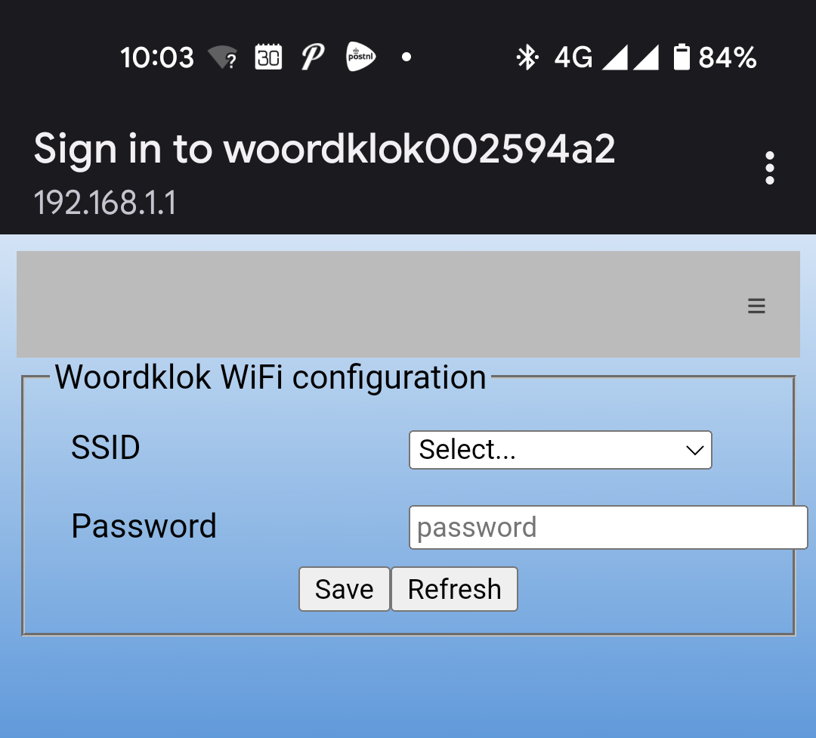
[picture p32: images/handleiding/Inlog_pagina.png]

- Indien u de Pop-up niet krijgt zoals bij sommige Samsung telefoons. 
- drukt u lang op de woordklokxxxxxx wifi en daarna op router beheer zoals: \
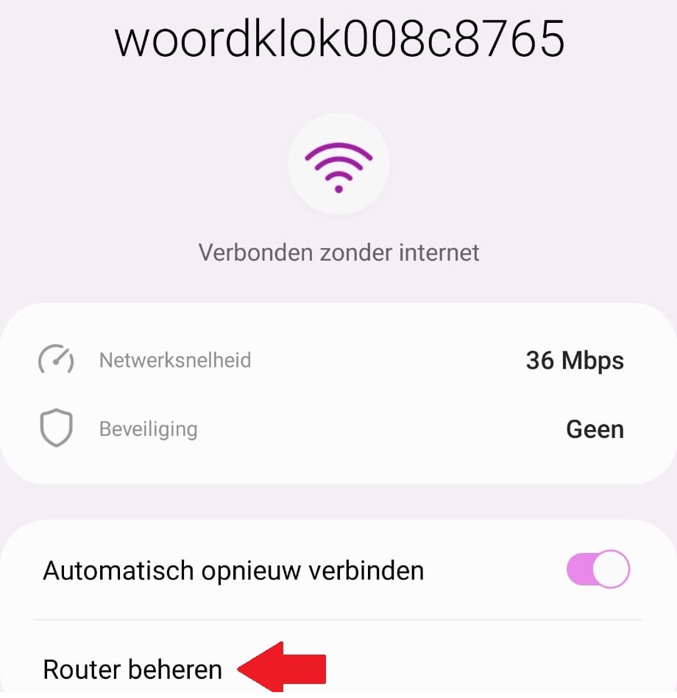
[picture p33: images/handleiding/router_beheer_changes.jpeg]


### Stap 3
- Selecteer uw WiFi Thuis door op de `Select` te klikken
- Voer het wachtwoord in van uw Thuis netwerk
- klik op Save om de instelling te bevestigen
- De klok zal herstarten en verbinding maken met uw Thuisnetwerk

## Gebruik
De Klok is nu verbonden met uw Thuis netwerk en kan de tijd van het internet halen. Indien u de kleuren wil aanpassen of het gedrag van de klok dan kunt u de onderstaande stappen volgen.
### Stap 1
- Weet u het IP adres al? ga naar Stap 2
- Herstart de klok door de voeding 5 seconde los te halen en weer aan te sluiten
- Neem wat afstand van de klok om de cijfers goed te kunnen lezen
- Schrijf de cijfers op die langs gelopen komen: \
- Voorbeeld: 192.168.178.13 of 192.168.2.84 (meestal is alleen het laatste getal anders)
- Op deze foto ziet u het getal 168 waarvan alleen 16 momenteel in beeld is \
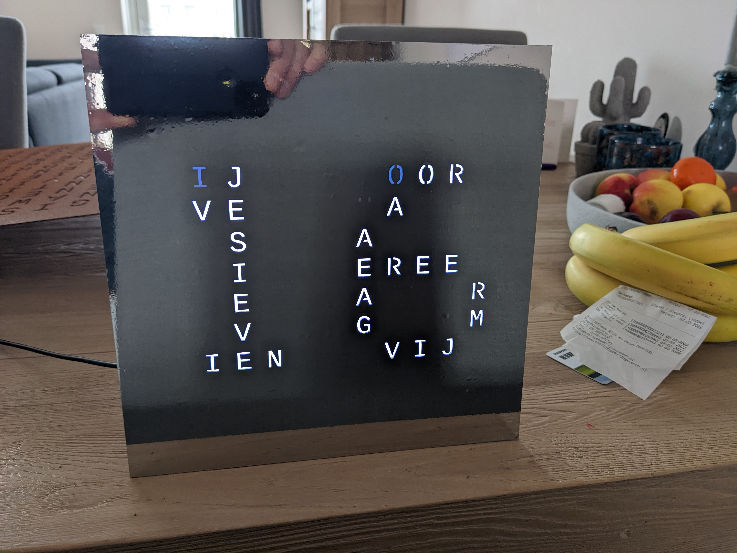
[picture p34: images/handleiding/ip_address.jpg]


### Stap 2
- Pak u telefoon/laptop/tablet
- Controller dat u verbonden bent met uw Thuisnetwerk
- Open een browser (chrome, safarie, Edge, ..)
- Voer het IP adres in de adres balk en open de site \


### Stap 3
De website van de klok zal verschijnen, Linksboven kan het menu opengeklapt worden
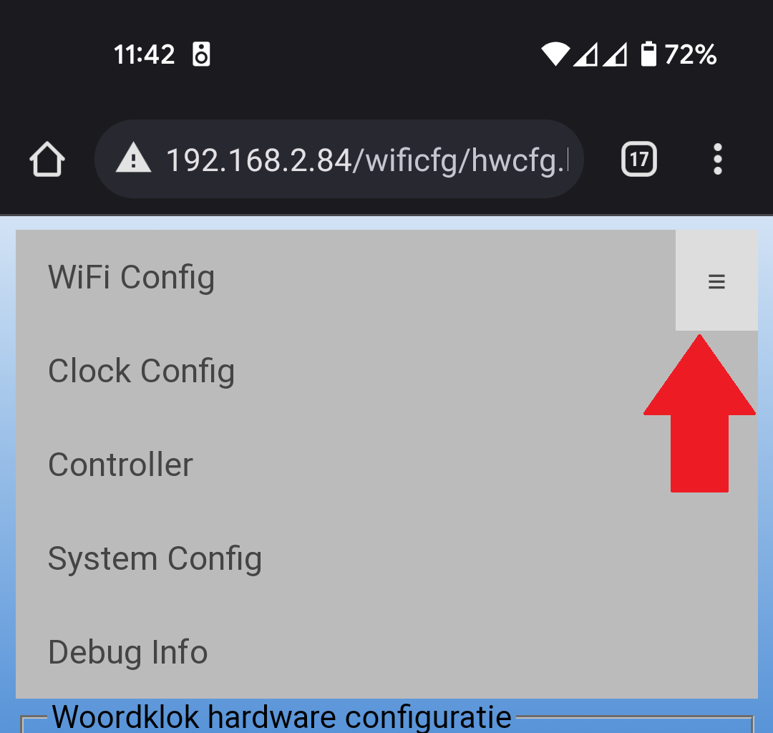
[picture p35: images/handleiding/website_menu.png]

- Clock Config
    - De kleur is de kleur van de tijd tekst
    - Tekst effect is het effect op de tijd (Uit, Random of Rainbow)
    - Helderheid van 0 tot 5 ingesteld, dit is een extra offset in de helderheid. (5 is het felst)
    - achtergrondkleur, is de kleur van alle letter die niet de tijd tekst weergeven.
    - Animaties, is een keuze van een aantal animaties tussen elke minuut overgang
    - Tekst, Is een aanpasbare tekst die als loopkrant langs kan komen.
    - Save, hiermee wordt de nieuwe instelling actief

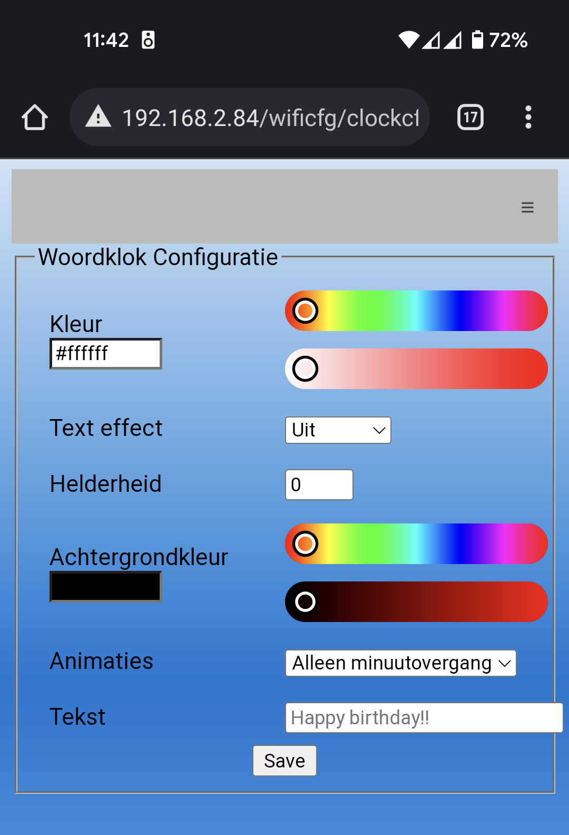
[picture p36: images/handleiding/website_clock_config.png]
    
- Wifi config
    - SSID is de naam van de wifi netwerk waarmee de klok moet verbinden.
    - Password, het wachtwoord van het wifi netwerk

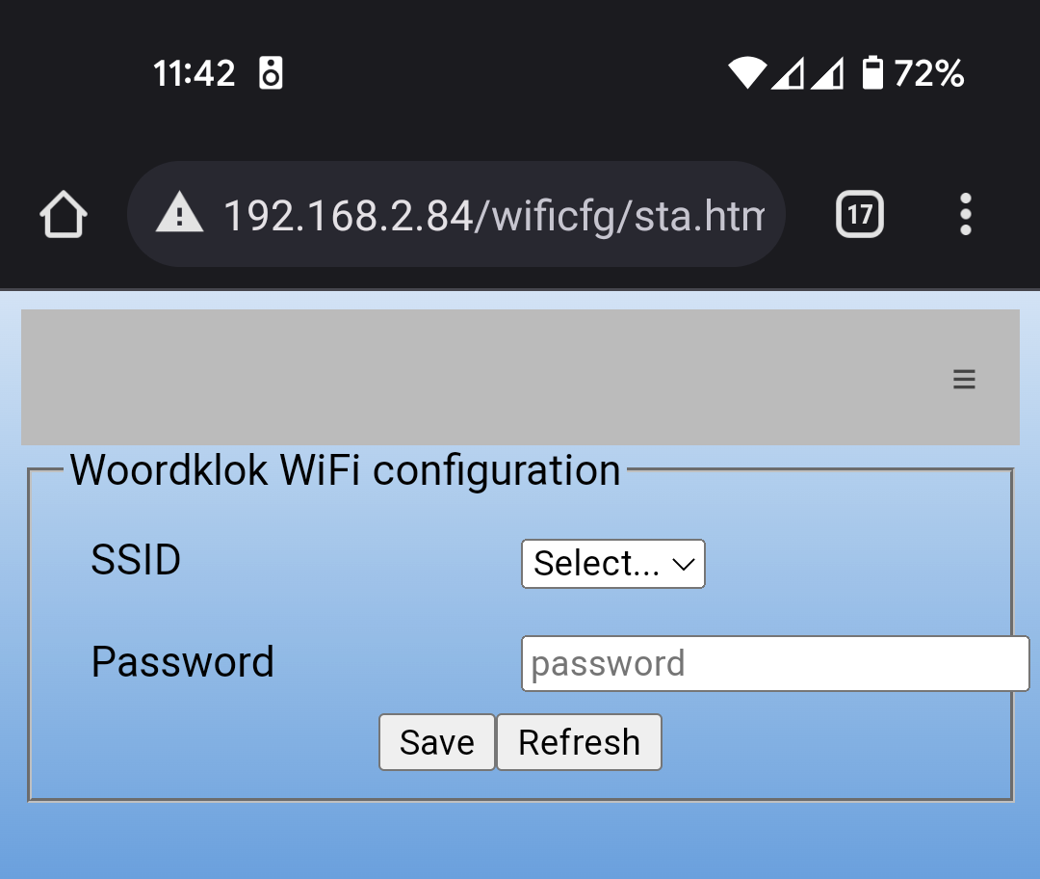
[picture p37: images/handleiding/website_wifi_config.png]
    
- Systeem Config
    - Hardware versie, 13x13 of 11x11 is het aantal letters in de lengte en breedte.
        - 11x11 is voor de klein of grote klok met 11x11 letters
        - 13x13 is voor letterplaat versie 1 50x50cm
        - 13x13 not Accurate is voor versie 1, waarbij de text Bijna en geweest gebruikt worde
        - 13x13 V2 is voor letterplaat versie 2, waarbij 16:46 -> Het is negentien voor vijf
        - 13x13 V2.1 is voor letterplaat versie 2, waarbij 16:46 -> Het is elf over half vijf.
    - Pixel type, is het type ledstrip
        - RGB is standaard voor kleine en oude klokken
        - RGBNW is standaard voor nieuwe groten klokken
    - Perfect inperfections, hiermee wordt er soms een willekeurige led aangezet
    - Hier ben ik, is een functie die lastig te gebruiken is. 
    - OTA fw server, Dit is de server waar de klok nieuwe FW kan ophalen
    
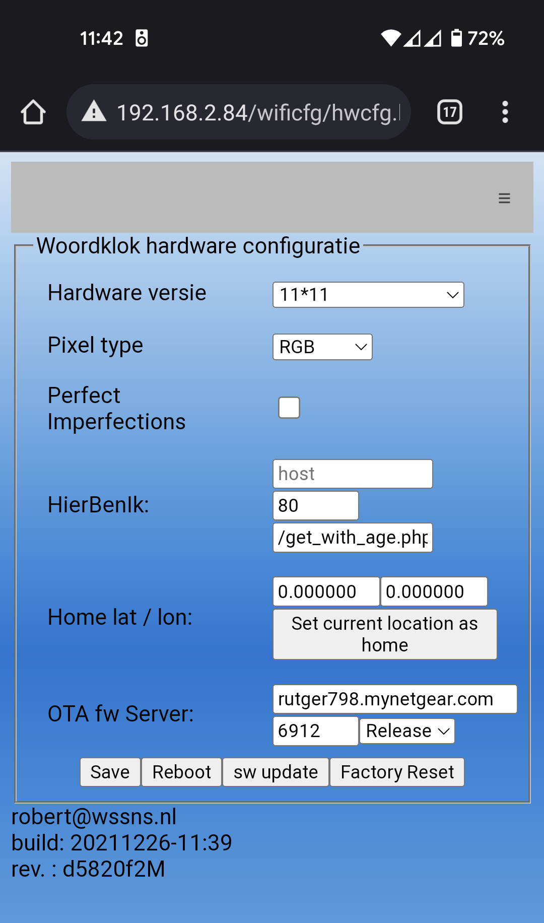
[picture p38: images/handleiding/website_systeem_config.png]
    

## Veel gestelde vragen
### Hoe vind ik de webpagina van de klok?
Herstart de klok, en lees het IP adres af vanaf een afstand, dit adres kunt u invoeren in een browser en de webpagina zal verschijnen

### Er brand altijd een rode letter in de hoek?
Uw klok kan momenteel geen verbinding maken met het internet, Probeer de klok te herstarten indien daarmee het probleem niet is verhopen is misschien uw WiFi veranderd volg de installatie stappen

### Hoe pas ik de kleur van de letter aan?
De kleur van de klok kan aangepast worden via de website. De website is via het IP adres van de klok beschikbaar

### Ik kan het IP adres niet lezen?
Neem wat afstand van de klok zodat u duidelijker cijfers zult zien.
Het IP adres komt langs als loopkrant text.

### Mijn Thuis Wifi staat niet in de lijst en nu?
Door op de `refresh` knop te klikken zal de klok opnieuw opzoek gaan naar WiFi netwerken in de buurt.
De klok verijst een 2.4GhZ WiFi netwerk, 5Ghz wordt niet ondersteund, vaak kunt u dit instellen op uw thuis netwerk.

### Mijn klok doet gek, de letters staan niet goed of de woorden kloppen niet?
Gezien de klok in twee maten verkocht worden kan het zijn dat de systeem instellingen van de klok niet meer goed staan, Dit kun u herstellen door:
- Onder de "system config" controlleer de "hardware versie"
    - Als uw klok 11 rijen heeft en 11 kolomen dan moet het 11x11 zijn
    - Als uw klok 13 rijen heeft en 13 kolomen dan moet het 13x13 zijn als er "viertien" op de plaat staat
    - Als uw klok 13 rijen heeft en 13 kolomen dan moet het 13x13 V2 zijn als er "veertien" op de plaat staat
- Onder de "system config" controlleer de "pixel type"
    - Al het onderste deel van de klok niet verlicht is heeft u waarschijnlijk RGBNW
    - Anders kunt u vragen welke variant u heeft
- Na elke wijziging moet u op save knop drukken 2 seconde wachten en daarna op de reboot knop.

### Firmeware update
U kunt de firmware van de klok updaten door de onderstaande stappen te doen.
- Ga via uw telefoon of laptop naar het ip address van de klok
- Daarna naar "Systeem config"
- Schrijf de "build date" op (staat onderin de pagina)
- Pas het "OTA fw server" veld aan naar "http://download.wssns.nl" "8090" "Release"
- Druk op "Save" knop, en wacht 2 seconde
- Druk op "sw update" knop
- Uw klok herstart, controlleer of het gelukt is door naar "Systeem config" te gaan en de build date te vergelijken.

### De fabrieks instellingen terug zetten
De klok terug zetten naar fabrieksinstellingen:
- Ga via uw telefoon of laptop naar het ip address van de klok
- Daarna naar "Systeem config"
- Druk op "Factory Reset" knop

### Mijn klok is kapot en nu?
Neem contact op zolang u vriendelijk blijft is er een hoop mogelijk.

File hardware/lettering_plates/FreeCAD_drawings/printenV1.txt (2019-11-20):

HETGISENUZELF
BIJNAWDERTIEN
DRIENEGENTIEN
ZEVENTIENVIJF
TWEENVIERTIEN
ACHTTIENKWART
ZESTIENTWAALF
OVERVOOROHALF
VIJFWACHTDRIE
TWEENZESZEVEN
TIENTWAALFELF
BVIERNEGENRWA
VUURAGEWEESTU

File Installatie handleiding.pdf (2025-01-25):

Installatie handleiding.md | 2025-01-25

# Installatie handleiding

Deze handleiding zal stapsgewijs uitleggen hoe u de klok kunt installeren en gebruiken. Het laatste hoofdstuk zal veel gestelde vragen beantwoorden.

## Installatie

De klok haalt zijn tijd op vanaf het internet, Dit kan de klok alleen doen zodra de klok verbind met uw WiFi thuis. Nadat de klok met uw WiFi is verbonden zal de klok altijd de goede tijd weergeven.

### Stap 1:

Sluit de USB aan op een USB adapter van minimaal 1A, Sluit de andere kant aan op de controller van de klok

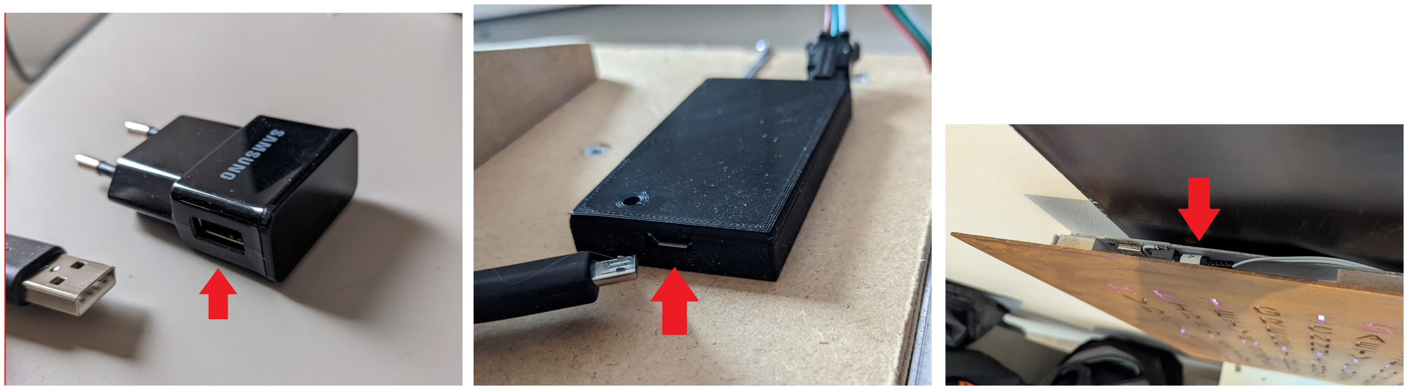
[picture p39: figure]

Uw klok zal opstarten en de onderstaande tekst zal over het scherm scrollen No WiFi Connect to woordklok WiFi and sign in

### Stap 2

Open op uw telefoon/Laptop/tablet de WiFi instellingen
Zoek naar de Wifi met de naam woordklokxxxxxx (de x maakt uw klok uniek)


Verbind met de woordklok WiFi
Klik op de Pop-up om in te loggen(de meeste telefoons doen dit automatisch):

Als alles goed is gegaan ziet u nu deze pagina:


Indien u de Pop-up niet krijgt zoals bij sommige Samsung telefoons.
drukt u lang op de woordklokxxxxxx wifi en daarna op router beheer zoals:


### Stap 3

Selecteer uw WiFi Thuis door op de Select te klikken
Voer het wachtwoord in van uw Thuis netwerk
klik op Save om de instelling te bevestigen
De klok zal herstarten en verbinding maken met uw Thuisnetwerk

## Gebruik

De Klok is nu verbonden met uw Thuis netwerk en kan de tijd van het internet halen. Indien u de kleuren wil aanpassen of het gedrag van de klok dan kunt u de onderstaande stappen volgen.

### Stap 1

Weet u het IP adres al? ga naar Stap 2
Herstart de klok door de voeding 5 seconde los te halen en weer aan te sluiten
Neem wat afstand van de klok om de cijfers goed te kunnen lezen
Schrijf de cijfers op die langs gelopen komen: \
Voorbeeld: 192.168.178.13 of 192.168.2.84 (meestal is alleen het laatste getal anders) Op deze foto ziet u het getal 168 waarvan alleen 16 momenteel in beeld is


### Stap 2

Pak u telefoon/laptop/tablet

Controller dat u verbonden bent met uw Thuisnetwerk Open een browser (chrome, safarie, Edge, ..)
Voer het IP adres in de adres balk en open de site

### Stap 3

De website van de klok zal verschijnen, Linksboven kan het menu opengeklapt worden


Clock Config

De kleur is de kleur van de tijd tekst
Tekst effect is het effect op de tijd (Uit, Random of Rainbow)
Helderheid van 0 tot 5 ingesteld, dit is een extra offset in de helderheid. (5 is het felst)
achtergrondkleur, is de kleur van alle letter die niet de tijd tekst weergeven. Animaties, is een keuze van een aantal animaties tussen elke minuut overgang Tekst, Is een aanpasbare tekst die als loopkrant langs kan komen.
Save, hiermee wordt de nieuwe instelling actief


Wifi config

SSID is de naam van de wifi netwerk waarmee de klok moet verbinden. Password, het wachtwoord van het wifi netwerk


Systeem Config

Hardware versie, 13x13 of 11x11 is het aantal letters in de lengte en breedte. 11x11 is voor de klein of grote klok met 11x11 letters
13x13 is voor letterplaat versie 1 50x50cm
13x13 not Accurate is voor versie 1, waarbij de text Bijna en geweest gebruikt worde
13x13 V2 is voor letterplaat versie 2, waarbij 16:46 -> Het is negentien voor vijf
13x13 V2.1 is voor letterplaat versie 2, waarbij 16:46 -> Het is elf over half vijf. Pixel type, is het type ledstrip
RGB is standaard voor kleine en oude klokken
RGBNW is standaard voor nieuwe groten klokken
Perfect inperfections, hiermee wordt er soms een willekeurige led aangezet Hier ben ik, is een functie die lastig te gebruiken is.
OTA fw server, Dit is de server waar de klok nieuwe FW kan ophalen

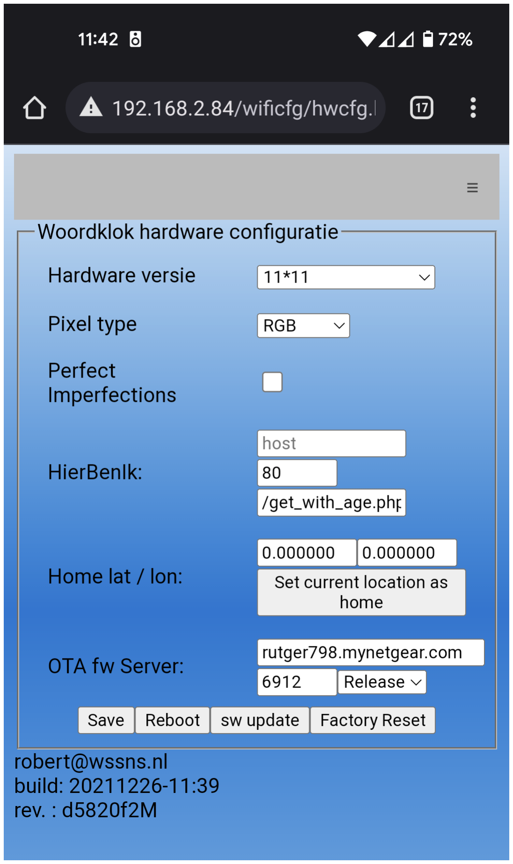
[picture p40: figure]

## Veel gestelde vragen

### Hoe vind ik de webpagina van de klok?

Herstart de klok, en lees het IP adres af vanaf een afstand, dit adres kunt u invoeren in een browser en de webpagina zal verschijnen

### Er brand altijd een rode letter in de hoek?

Uw klok kan momenteel geen verbinding maken met het internet, Probeer de klok te herstarten indien daarmee het probleem niet is verhopen is misschien uw WiFi veranderd volg de installatie stappen

### Hoe pas ik de kleur van de letter aan?

De kleur van de klok kan aangepast worden via de website. De website is via het IP adres van de klok beschikbaar

### Ik kan het IP adres niet lezen?

Neem wat afstand van de klok zodat u duidelijker cijfers zult zien. Het IP adres komt langs als loopkrant text.

### Mijn Thuis Wifi staat niet in de lijst en nu?

Door op de refresh knop te klikken zal de klok opnieuw opzoek gaan naar WiFi netwerken in de buurt. De klok verijst een 2.4GhZ WiFi netwerk, 5Ghz wordt niet ondersteund, vaak kunt u dit instellen op uw thuis netwerk.

### Mijn klok doet gek, de letters staan niet goed of de woorden kloppen niet?

Gezien de klok in twee maten verkocht worden kan het zijn dat de systeem instellingen van de klok niet meer goed staan, Dit kun u herstellen door:

Onder de "system config" controlleer de "hardware versie"
Als uw klok 11 rijen heeft en 11 kolomen dan moet het 11x11 zijn
Als uw klok 13 rijen heeft en 13 kolomen dan moet het 13x13 zijn als er "viertien" op de plaat staat
Als uw klok 13 rijen heeft en 13 kolomen dan moet het 13x13 V2 zijn als er "veertien" op de plaat staat
Onder de "system config" controlleer de "pixel type"
Al het onderste deel van de klok niet verlicht is heeft u waarschijnlijk RGBNW Anders kunt u vragen welke variant u heeft
Na elke wijziging moet u op save knop drukken 2 seconde wachten en daarna op de reboot knop.

### Firmeware update

U kunt de firmware van de klok updaten door de onderstaande stappen te doen.

Ga via uw telefoon of laptop naar het ip address van de klok
Daarna naar "Systeem config"
Schrijf de "build date" op (staat onderin de pagina)
Pas het "OTA fw server" veld aan naar "http://download.wssns.nl" "8090" "Release" Druk op "Save" knop, en wacht 2 seconde
Druk op "sw update" knop

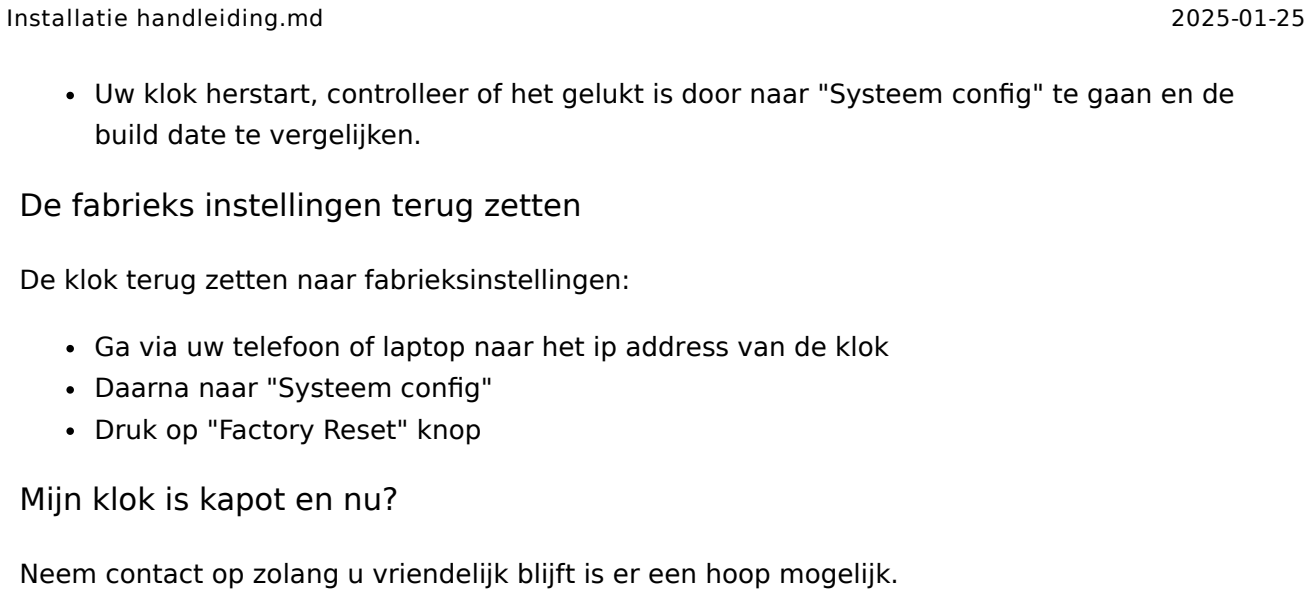
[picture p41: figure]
build date te vergelijken.; De fabrieks instellingen terug zetten; Daarna naar "Systeem config" Druk op "Factory Reset" knop; Mijn klok is kapot en nu?

Uw klok herstart, controlleer of het gelukt is door naar "Systeem config" te gaan en de

De klok terug zetten naar fabrieksinstellingen:

Ga via uw telefoon of laptop naar het ip address van de klok

Neem contact op zolang u vriendelijk blijft is er een hoop mogelijk.

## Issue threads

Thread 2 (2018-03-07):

Personalize via system config web page

thekr1s, 2018-03-07:
Currently personalisation for rutger and robert is done via SSID. Personal stuff must be removed from the archive

Rutger798, 2019-12-30:
dus dan worden de volgende items instelbaar:
hierbenik: URL, port, request
ota-tftp: URL, port
wel of geen perfect imperfections

Alleen de "he lise en evi wacht even" weet ik even niet iets generiek voor te verzinnen

thekr1s, 2020-01-04:
Oh cool dat je dit oppakt. Was ook het eerste wat ik wilde aanpakken.!

De optie "wel of geen perfect imperfections" is onder protest!!

Rutger798, 2020-01-04:
Haha dan moet je protesteren tegen Suzanne...
Maar heb ook al een pull request gestuurd ;)

Closed 2020-01-05.

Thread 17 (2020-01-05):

When in AP mode enable HTTP redirect

Rutger798, 2020-01-05:
This way when connecting to the clock for the first time a popup will show to enter the credentials

thekr1s, 2020-01-05:
I have tried this. I think it was called 'captive dns'. But that did not work well back then. It is good to give it a retry.

Rutger798, 2020-01-05:
Voor de Cloudia heet het HTTP redirect;), maar bedankt voor de tip ik ga nog even verder zoeken op "captive dns"
Voor de arduino ESP is het wel gelukt: https://github.com/tzapu/WiFiManager

thekr1s, 2020-01-05:
Er zit al een dns servertje in de woordklok. Als je die op elk request zijn eigennipadres laat retourneren is het volgens mij al goed. Was volgens mij een probleem dat hij omkwam in de requests ofzo... Daarom laat ik alleen zijn ip retouerneren als er woordklok in de naam staat oid.

Rutger798, 2020-01-05:
Zag inderdaad wel een hoop van de zelfde code, maar ik zie dat https://github.com/maximkulkin/esp-wifi-config gebruikt maakt van een nieuwe versie van esp-open-rtos......
En ik zie dat er een patch is gemaakt in de dhcpserver.

Rutger798, 2020-01-05:
Haha Ik heb het esp-open-rtos geupdate naar de laatste versie maar er gaat nog iets mis met de aansturing van het display. maar daar ga ik een ander keertje mee klooien

thekr1s, 2020-01-05:
Oh cool! Heb je veel moeten doen? Er zitten volgens mij een paar hacks in het OS. Bijv om eigen ip adrs te achterhalen..

Rutger798, 2020-01-05:
mwa viel wel mee, en veel patches zijn niet meer nodig door de nieuwe versie. maar bijna alles werkt alleen de ledstip wordt niet correct aangestuurd, de kleur klopt niet en hij zit er soms een letter naast.... gaat er bij jou dan toevallig een lampje branden ?

thekr1s, 2020-01-05:
Klinkt als dat de timing niet gehaald wordt. Als ik het goed heb wordt de timing geregeld via spi. Dan zou er iets in de spi driver zitten.
Als je het anders pusht, wil ik er wel even naar kijken...

Rutger798, 2020-01-07:
Het OS is geupdate in https://github.com/thekr1s/esp8266_wordclock/pull/18 na de merge ga ik het nog een keer proberen.

Rutger798, 2020-05-01:
Issue is solved in https://github.com/thekr1s/esp8266_wordclock/pull/32

Rutger798, 2020-07-13:
Retry:
Get Idle time by low prio task
?Sem between setting save and irq delay?
split wifi cfg into webpage and wificfg
retry captive DNS

Closed 2020-08-06.

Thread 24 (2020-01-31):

Klok op hol

thekr1s, 2020-01-31:
After upgrading esp-open-rtos, the clock runs wild. Continuously switching time to a random time.

Rutger798, 2020-02-22:
Ik hoopte dat de stack vergroting het zou oplossen maar ik heb het nog een keer gezien, Gezien de links boven de led rood brand tijdens het flippen lijkt het me iets wifi/sntp gerelateerd.

thekr1s, 2020-02-22:
Dit is inderdaad sntp. SNTP stelt de clock rate in. Ik vermoed dat door omstandigheden deze clock rate helemaal fout kom te staat en de tijd als een dolle voortschreidt.

in sntp_update_rtc() in sntp_fun.c wordt onderstaande aangeroepen.
	cal = sdk_system_rtc_clock_cali_proc();

mijn vermoeden gaat naar die hoek. Maar het reproduceert zo moeilijk. Debuggen lastig.
Zat wel te denken of het te detecteren is in sw. vermoedelijk wel

thekr1s, 2020-02-22:
Mogelijke workaround:
Detecteer in sntp_client.c ron regel 65 dat _rtcTicsPerSec een absurde waarde heeft. Of vraag tijd op via time() en zie dat het niet klopt met de 5 sec wachttijd.
Als fout, dan sntp_stop() en opnieuw sntp_init() aanroepen.

Rutger798, 2020-02-22:
Ik ga dan daaromheen wat meer logging toevoegen en dan een Klok aan mn werk PC koppelen zodat ik hopelijk kan gaan zien wat er mis is, Dan maakt ik de workaround er in om te detecteren dat het mis gaat
Ik zie het namelijk zelf echt maar 1 keer per week ofzo....

Rutger798, 2020-04-15:
`*15-04 14:39:21*SNTP RTC adjust: 0.004 s; 265.692 ppm over 15.066 s; cal: 25540
*15-04 14:39:34*Time: Tue Apr 14 22:46:27 2020 TSdiff: -53587 diff: 160245/160214, _rtcTimePerSec: 160245
*15-04 14:39:35*SNTP RTC counter wrappedSNTP RTC counter wrappedSNTP RTC counter wrappedSNTP RTC counter wrappedSNTP RTC counter wrappedSNTP RTC counter wrappedSNTP RTC counter wrappedSNTP RTC counter wrappedERROR RHU1
*15-04 14:39:35*Time: Sun Apr 12 11:13:53 2020 TSdiff: -187559 diff: 160156/160245, _rtcTimePerSec: 160156
*15-04 14:39:36*SNTP RTC counter wrappedSNTP RTC counter wrappedSNTP RTC counter wrappedSNTP RTC counter wrappedSNTP RTC counter wrappedSNTP RTC counter wrappedSNTP RTC counter wrappedSNTP RTC adjust: 455502.463 s; 30256393037.520 ppm over 15.055 s; cal: 25553
*15-04 14:39:36*Time: Wed Apr 15 13:39:37 2020 TSdiff: 294738 diff: 159653/160156, _rtcTimePerSec: 159653
*15-04 14:39:51*SNTP RTC adjust: 0.005 s; 349.005 ppm over 15.049 s; cal: 25546
*15-04 14:40:06*SNTP RTC adjust: -0.004 s; -291.821 ppm over 15.067 s; cal: 25554
`

thekr1s, 2020-04-16:
Ik kan je conclusie niet volgen, ik weet ook niet wat die TSdiff is.
Ik heb het idee dat de calibratie niet goed gaat waardoor de timer als een dolle loopt. Omdat hij zo snel loopt, wrapt de timer ook snel. Daardoor wordt TSdiff negatief. Is niet zo dat de klok terud loopt. En dat wrappen is m.i. een gevolg en niet de oorzaak...

Rutger798, 2020-04-17:
Het was ook meer mn eigen naslag werk,
maar TSdiff is de timestamp diff van time(NULL) voor de delay en time(NULL) na de delay

de SNTP RTC counter wrapped zou je maar 1 keer moeten zien omdat de counter in de zelfde functie uit zn wrapping wordt gehaald.

Nadat ik een ik de pull request van https://github.com/SuperHouse/esp-open-rtos/pull/148 werkend heb gekregen heb ik het niet meer gezien.

Rutger798, 2020-04-18:
Created a pull request to the SuperHouse git repo,
https://github.com/SuperHouse/esp-open-rtos/pull/744

But for now its fixed in a fork from SuperHouse repo

Closed 2020-04-20.

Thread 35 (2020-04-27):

OTA firmware update crashes

thekr1s, 2020-04-27:
Looks like since the RTOS is updated the software update fails.
Investigations up to now show chaos. Crashes at different locations. Looks like head / stack problems

Rutger798, 2020-04-28:
Please try to reproduct in captive DNS

thekr1s, 2020-04-28:
It also reproduces in that Captive DNS branch

Rutger798, 2020-05-14:
Dit lag aan de manier hoe jij flashed? (dus mag die dicht?)

Closed 2020-07-10.

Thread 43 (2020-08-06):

Button + settings safe Event driven maken

Rutger798, 2020-08-06:
zorg er voor dat de Buttons via IRQ afgehandeld worden en dan netjes de status op het scherm laat zien.
Zorg er voor dat de settings mbv een Semaphore worden opgeslagen ipv het interrupt vlaggetje in de delay functie

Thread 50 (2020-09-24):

MDNS + static IP

Rutger798, 2020-09-24:
Enable MDNS (should work for windows apple devices)

In the WiFi configuration web-page
Make it possible to set a static IP address & GW & subnet mask
And a fielt for the MDNS name with default "woordklok"

Example:

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

thekr1s, 2020-09-24:
Ik ga dit niet maken. Levert te weinig op.

Rutger798, 2020-09-24:
Jammer :)
Dan komt het wel een keertje.

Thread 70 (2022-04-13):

Spilt HW configuration and settings

Rutger798, 2022-04-13:
Currently when clock's are set to factory reset there hw configuration is reset.
In case of a 13x13 clock, this can reset to 11x11 which makes the clock unreadable

alternative:
make multiple target files and get the proper file when updating

Closed 2022-05-30.

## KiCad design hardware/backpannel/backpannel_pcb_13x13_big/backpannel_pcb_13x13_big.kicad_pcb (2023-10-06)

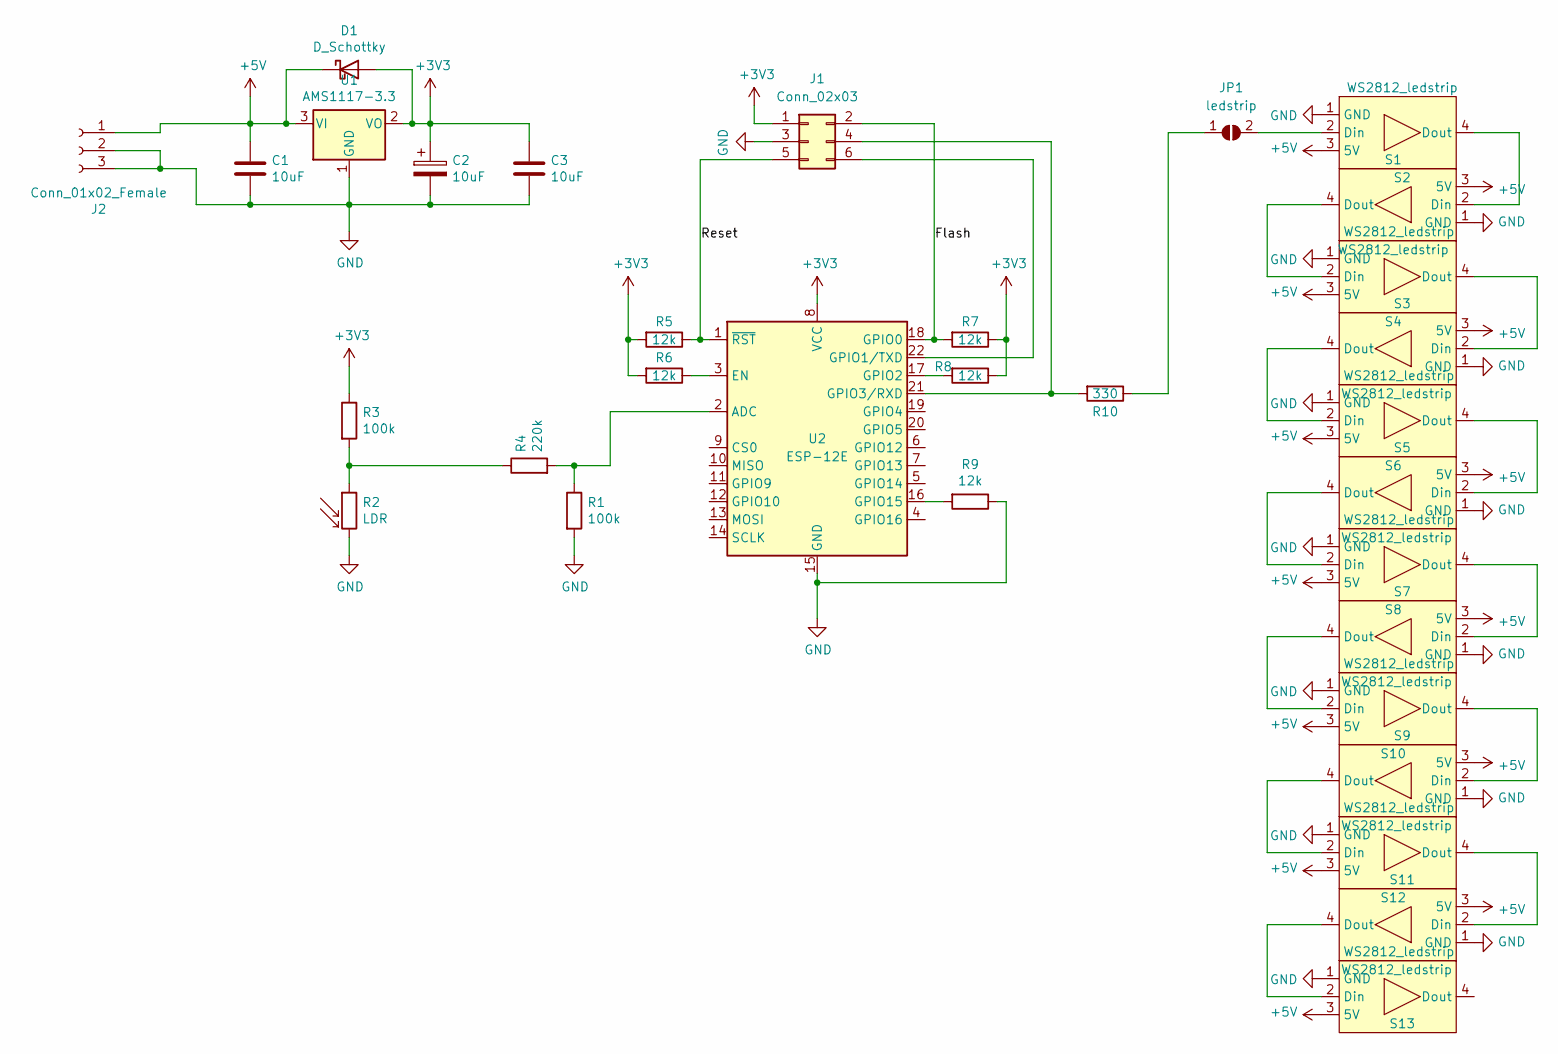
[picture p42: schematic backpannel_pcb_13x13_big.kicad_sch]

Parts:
C1, C3: 10uF; C_0805_2012Metric_Pad1.18x1.45mm_HandSolder
C2: 10uF; CP_Elec_6.3x5.4
D1: D_Schottky; D_0805_2012Metric_Pad1.15x1.40mm_HandSolder
J1: Conn_02x03; PinHeader_2x03_P2.54mm_Vertical
J2: Conn_01x02_Female; BarrelJack_CLIFF_FC681465S_SMT_Horizontal
JP1: ledstrip; SolderJumper-2_P1.3mm_Open_RoundedPad1.0x1.5mm
R1, R3: 100k; R_0805_2012Metric_Pad1.20x1.40mm_HandSolder
R2: LDR; R_LDR_5.1x4.3mm_P3.4mm_Vertical
R4: 220k; R_0805_2012Metric_Pad1.20x1.40mm_HandSolder
R5, R6, R7, R8, R9: 12k; R_0805_2012Metric_Pad1.20x1.40mm_HandSolder
R10: 330; R_0805_2012Metric_Pad1.20x1.40mm_HandSolder
S1, S2, S3, S4, S5, S6, S7, S8, S9, S10, S11, S12, S13: WS2812_ledstrip; WS2812_ledstrip_30leds_meter
U1: AMS1117-3.3; SOT-223-3_TabPin2
U2: ESP-12E

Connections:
+3V3: C2.1, C3.1, D1.2 (A), J1.1, R3.1, R5.2, R6.2, R7.1, R8.1, U1.2 (VO), U2.8 (VCC)
+5V: C1.1, D1.1 (K), J2.1, S1.3 (5V), S2.3 (5V), S3.3 (5V), S4.3 (5V), S5.3 (5V), S6.3 (5V), S7.3 (5V), S8.3 (5V), S9.3 (5V), S10.3 (5V), S11.3 (5V), S12.3 (5V), S13.3 (5V), U1.3 (VI)
/Flash: J1.2, R7.2, U2.18 (GPIO0)
/Reset: J1.5, R5.1, U2.1 (~RST)
GND: C1.2, C2.2, C3.2, J1.3, J2.2, J2.3, R1.2, R2.2, R9.1, S1.1 (GND), S2.1 (GND), S3.1 (GND), S4.1 (GND), S5.1 (GND), S6.1 (GND), S7.1 (GND), S8.1 (GND), S9.1 (GND), S10.1 (GND), S11.1 (GND), S12.1 (GND), S13.1 (GND), U1.1 (GND), U2.15 (GND)
unnamed: J1.4, R10.2, U2.21 (GPIO3/RXD)
unnamed: J1.6, U2.22 (GPIO1/TXD)
unnamed: JP1.1 (A), R10.1
unnamed: JP1.2 (B), S1.2 (Din)
unnamed: R1.1, R4.2, U2.2 (ADC)
unnamed: R2.1, R3.2, R4.1
unnamed: R6.1, U2.3 (EN)
unnamed: R8.2, U2.17 (GPIO2)
unnamed: R9.2, U2.16 (GPIO15)
unnamed: S1.4 (Dout), S2.2 (Din)
unnamed: S2.4 (Dout), S3.2 (Din)
unnamed: S3.4 (Dout), S4.2 (Din)
unnamed: S4.4 (Dout), S5.2 (Din)
unnamed: S5.4 (Dout), S6.2 (Din)
unnamed: S6.4 (Dout), S7.2 (Din)
unnamed: S7.4 (Dout), S8.2 (Din)
unnamed: S8.4 (Dout), S9.2 (Din)
unnamed: S9.4 (Dout), S10.2 (Din)
unnamed: S10.4 (Dout), S11.2 (Din)
unnamed: S11.4 (Dout), S12.2 (Din)
unnamed: S12.4 (Dout), S13.2 (Din)

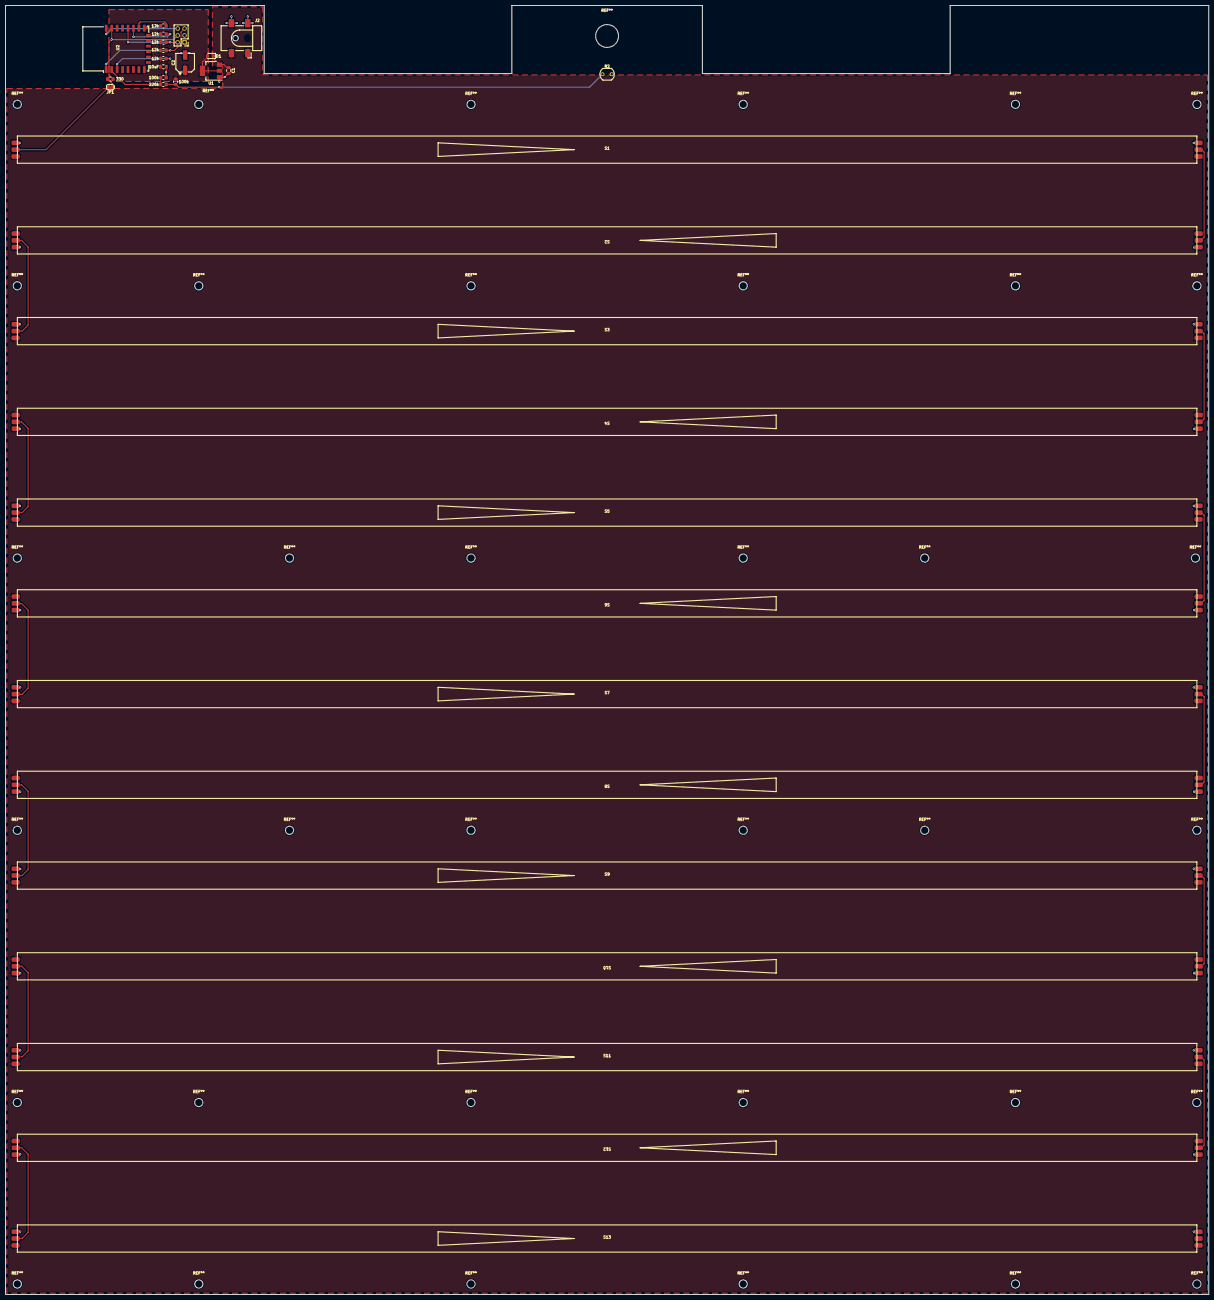
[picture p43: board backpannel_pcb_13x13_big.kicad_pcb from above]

Board: 2 copper layers, 442.0 x 473.5 mm, 32 parts (0 on the bottom side), 26 nets.

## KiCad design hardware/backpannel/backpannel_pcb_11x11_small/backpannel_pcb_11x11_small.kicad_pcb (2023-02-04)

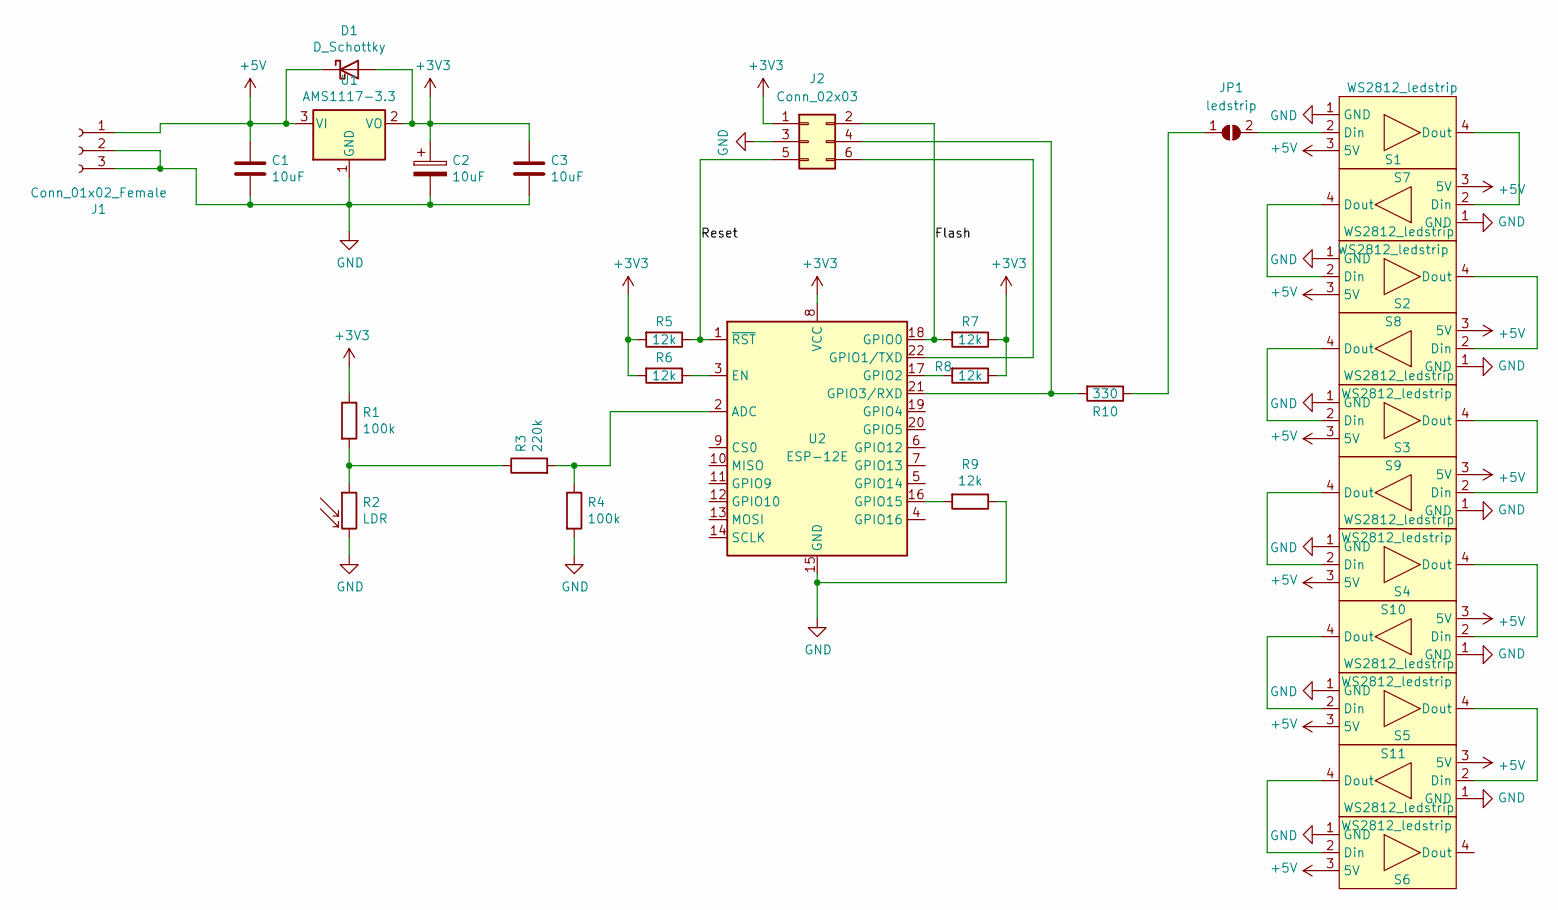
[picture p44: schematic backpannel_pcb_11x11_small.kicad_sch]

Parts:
C1, C3: 10uF; C_0805_2012Metric_Pad1.18x1.45mm_HandSolder
C2: 10uF; CP_Elec_6.3x5.4
D1: D_Schottky; D_0805_2012Metric_Pad1.15x1.40mm_HandSolder
J1: Conn_01x02_Female; BarrelJack_CLIFF_FC681465S_SMT_Horizontal
J2: Conn_02x03; PinHeader_2x03_P2.54mm_Vertical
JP1: ledstrip; SolderJumper-2_P1.3mm_Open_RoundedPad1.0x1.5mm
R1, R4: 100k; R_0805_2012Metric_Pad1.20x1.40mm_HandSolder
R2: LDR; R_LDR_5.1x4.3mm_P3.4mm_Vertical
R3: 220k; R_0805_2012Metric_Pad1.20x1.40mm_HandSolder
R5, R6, R7, R8, R9: 12k; R_0805_2012Metric_Pad1.20x1.40mm_HandSolder
R10: 330; R_0805_2012Metric_Pad1.20x1.40mm_HandSolder
S1, S2, S3, S4, S5, S6, S7, S8, S9, S10, S11: WS2812_ledstrip; WS2812_ledstrip_60leds_meter
U1: AMS1117-3.3; SOT-223-3_TabPin2
U2: ESP-12E

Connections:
+3V3: C2.1, C3.1, D1.2 (A), J2.1, R1.1, R5.2, R6.2, R7.1, R8.1, U1.2 (VO), U2.8 (VCC)
+5V: C1.1, D1.1 (K), J1.1, S1.3 (5V), S2.3 (5V), S3.3 (5V), S4.3 (5V), S5.3 (5V), S6.3 (5V), S7.3 (5V), S8.3 (5V), S9.3 (5V), S10.3 (5V), S11.3 (5V), U1.3 (VI)
/Flash: J2.2, R7.2, U2.18 (GPIO0)
/Reset: J2.5, R5.1, U2.1 (~RST)
GND: C1.2, C2.2, C3.2, J1.2, J1.3, J2.3, R2.2, R4.2, R9.1, S1.1 (GND), S2.1 (GND), S3.1 (GND), S4.1 (GND), S5.1 (GND), S6.1 (GND), S7.1 (GND), S8.1 (GND), S9.1 (GND), S10.1 (GND), S11.1 (GND), U1.1 (GND), U2.15 (GND)
unnamed: J2.4, R10.2, U2.21 (GPIO3/RXD)
unnamed: J2.6, U2.22 (GPIO1/TXD)
unnamed: JP1.1 (A), R10.1
unnamed: JP1.2 (B), S1.2 (Din)
unnamed: R1.2, R2.1, R3.1
unnamed: R3.2, R4.1, U2.2 (ADC)
unnamed: R6.1, U2.3 (EN)
unnamed: R8.2, U2.17 (GPIO2)
unnamed: R9.2, U2.16 (GPIO15)
unnamed: S1.4 (Dout), S7.2 (Din)
unnamed: S2.2 (Din), S7.4 (Dout)
unnamed: S2.4 (Dout), S8.2 (Din)
unnamed: S3.2 (Din), S8.4 (Dout)
unnamed: S3.4 (Dout), S9.2 (Din)
unnamed: S4.2 (Din), S9.4 (Dout)
unnamed: S4.4 (Dout), S10.2 (Din)
unnamed: S5.2 (Din), S10.4 (Dout)
unnamed: S5.4 (Dout), S11.2 (Din)
unnamed: S6.2 (Din), S11.4 (Dout)

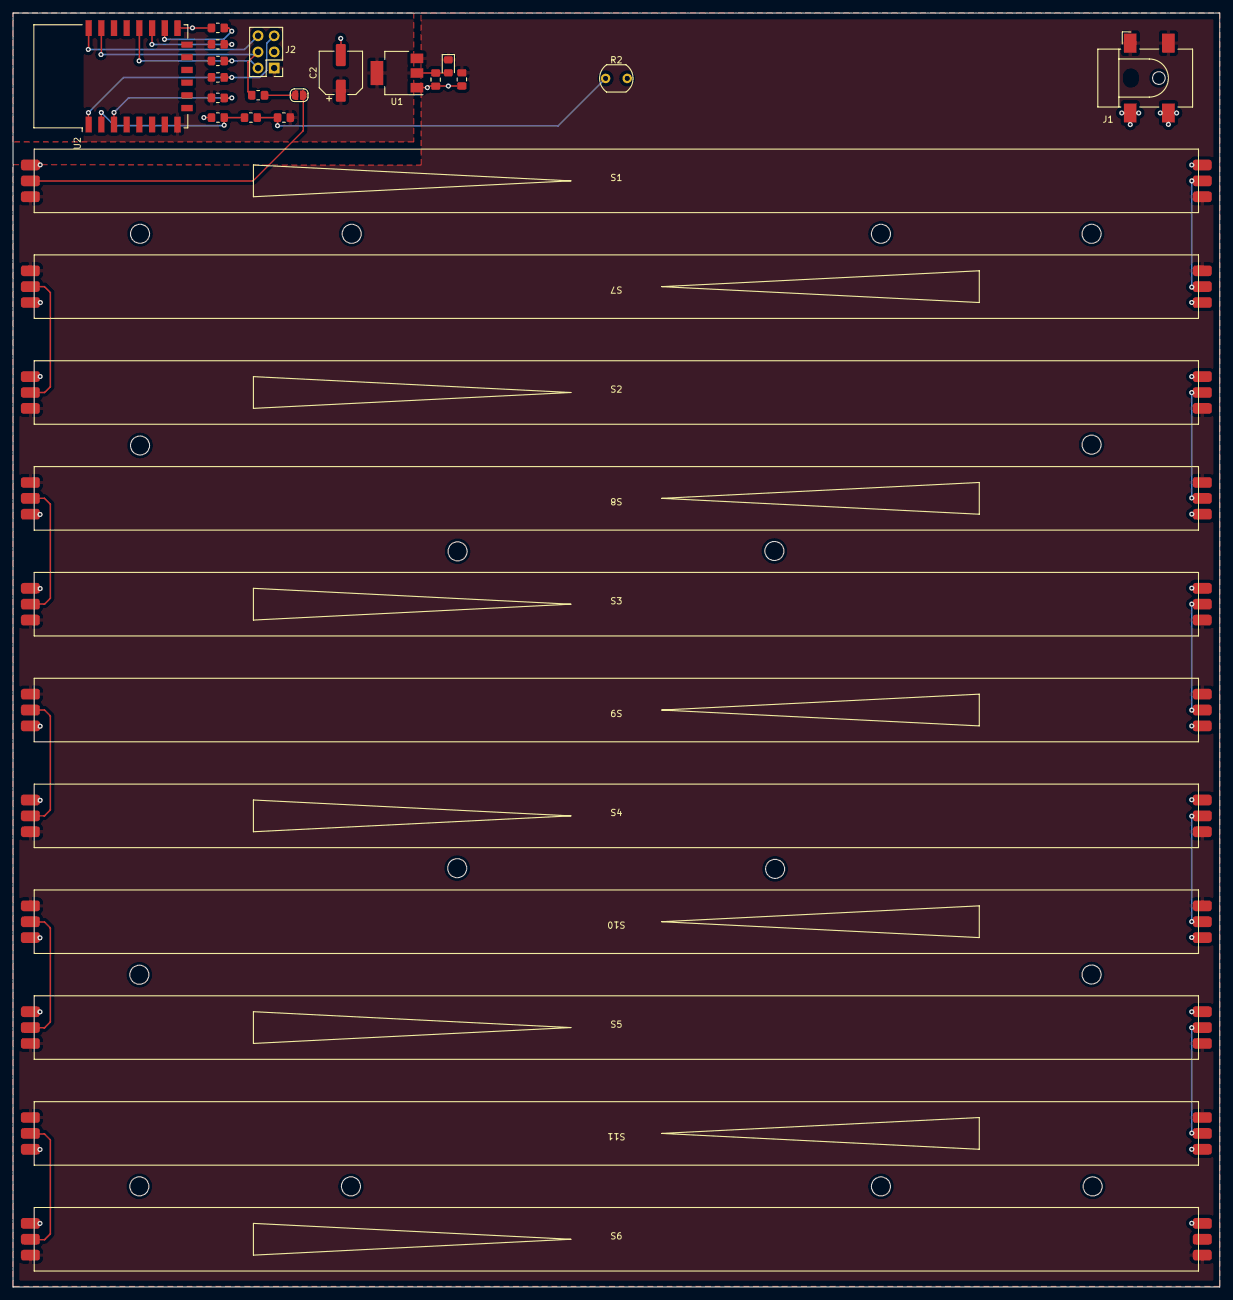
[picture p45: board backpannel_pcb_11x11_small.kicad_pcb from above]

Board: 2 copper layers, 190.0 x 200.6 mm, 30 parts (0 on the bottom side), 24 nets.

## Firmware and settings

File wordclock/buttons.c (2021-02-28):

#include <stdint.h>
#include <stdbool.h>
#include "espressif/esp_common.h"
#include <esp/gpio.h>
#include <time.h>
#include <sntp_client.h>

#include <event_handler.h>
#include "buttons.h"
#include "AddressableLedStrip.h"
#include "font.h"
#include "displaySettings.h"
#include "wordclock_main.h"
#include "settings.h"
#include "esp_glue.h"

static TColorIdx _colorIdx = COLOR_WHITE;
static const uint8_t _buttondownGpio = 4;   // NodeMCU pin D2
static const uint8_t _buttonModeGpio = 14;  //             D5
static const uint8_t _buttonUpGpio = 12;    //             D6

void interrupt_handler(uint8_t gpio_num){
	EvtHdlButtonStateChange();
}

void ButtonsInit(void){
    gpio_enable(_buttondownGpio, GPIO_INPUT);
    gpio_set_pullup(_buttondownGpio, true, true);
    //gpio_set_interrupt(_buttondownGpio, GPIO_INTTYPE_EDGE_ANY, interrupt_handler);
    gpio_enable(_buttonModeGpio, GPIO_INPUT);
    gpio_set_pullup(_buttonModeGpio, true, true);
    //gpio_set_interrupt(_buttonModeGpio, GPIO_INTTYPE_EDGE_ANY, interrupt_handler);
    gpio_enable(_buttonUpGpio, GPIO_INPUT);
    gpio_set_pullup(_buttonUpGpio, true, true);
    //gpio_set_interrupt(_buttonUpGpio, GPIO_INTTYPE_EDGE_ANY, interrupt_handler);

}

bool ButtonsDownPressed() {
	return (gpio_read(_buttondownGpio) == 0);
}
bool ButtonsModePressed() {
	return (gpio_read(_buttonModeGpio) == 0);
}
bool ButtonsUpPressed() {
	return (gpio_read(_buttonUpGpio) == 0);
}

bool ButtonsAllPressed() {

	return ButtonsDownPressed() && ButtonsModePressed() && ButtonsUpPressed();
}

bool ButtonsAnyPressed() {

	return ButtonsDownPressed() || ButtonsModePressed() || ButtonsUpPressed();
}

void ButtonShowMode(ButtonMode mode)
{
    AlsFill(0,0,0);
    switch (mode) {
    case BUTTONMODE_MINUTES:
        F5x7WriteChar(1,0,'M', g_brightness, g_brightness, g_brightness);
        F5x7WriteChar(1,5,'i', g_brightness, g_brightness, g_brightness);
        break;

    case BUTTONMODE_HOURS:
        F5x7WriteChar(1,0,'U', g_brightness, g_brightness, g_brightness);
        F5x7WriteChar(1,6,'U', g_brightness, g_brightness, g_brightness);
        break;

//  case BUTTONMODE_BRIGHTNESS:
//      F4x5WriteChar(1,0,'B', g_brightness, g_brightness, g_brightness);
//      F4x5WriteChar(1,5,'r', g_brightness, g_brightness, g_brightness);
//      break;

    case BUTTONMODE_RED:
        F5x7WriteChar(1,0,'R', g_brightness, g_brightness, g_brightness);
        F5x7WriteChar(1,6,'O', g_brightness, g_brightness, g_brightness);
        break;

    case BUTTONMODE_GREEN:
        F5x7WriteChar(1,0,'G', g_brightness, g_brightness, g_brightness);
        F5x7WriteChar(1,6,'R', g_brightness, g_brightness, g_brightness);
        break;

    case BUTTONMODE_BLUE:
        F5x7WriteChar(1,0,'B', g_brightness, g_brightness, g_brightness);
        F5x7WriteChar(1,6,'L', g_brightness, g_brightness, g_brightness);
        break;

    case BUTTONMODE_COLOR:
        F5x7WriteChar(1,0,'K', g_brightness, g_brightness, g_brightness);
        F5x7WriteChar(1,6,'L', g_brightness, g_brightness, g_brightness);
        break;

    case BUTTONMODE_ANIMATION:
        F5x7WriteChar(1,0,'A', g_brightness, g_brightness, g_brightness);
        F5x7WriteChar(1,6,'N', g_brightness, g_brightness, g_brightness);
        break;

    case BUTTONMODE_BRIGHTNESS:
        F5x7WriteChar(1,0,'B', g_brightness, g_brightness, g_brightness);
        F5x7WriteChar(1,6,'R', g_brightness, g_brightness, g_brightness);
        break;

    default:
        F5x7WriteChar(1,0,'E', g_brightness, g_brightness, g_brightness);
        F5x7WriteChar(1,6,'R', g_brightness, g_brightness, g_brightness);
        break;
    }
    AlsRefresh(ALSEFFECT_NONE);
}

/**
 *
 * @param mode
 * @param up  true: up false: down
 */
void ButtonHandleUpDown(ButtonMode mode, bool up)
{
//  uint32_t h,m,s;


    switch (mode) {
//  case BUTTONMODE_MINUTES:
//      TimeGet(&h, &m, &s);
//      m = up ? m + 1 : m - 1;
//      if (m > 0xf0000000) {
//          // wrap the minute
//          m = 59;
//      }
//      //m -= m % 5;
//      m %= 60;
//      TimeSet(h, m, 0, false);
//      break;
//
//  case BUTTONMODE_HOURS:
//      TimeGet(&h, &m, &s);
//      h = up ? h + 1 : h - 1;
//      if (h > 0xf0000000) {
//          // wrap the hour
//          h = 23;
//      }
//      h %= 24;
//      TimeSet(h, m, s, false);
//      break;

//  case BUTTONMODE_BRIGHTNESS:
//      _brightnessIdx = up ? _brightnessIdx + 1 : _brightnessIdx - 1;
//      if (_brightnessIdx == BRIGHTNESS_COUNT) {
//          _brightnessIdx = BRIGHTNESS_COUNT - 1;
//      }
//      if (_brightnessIdx == -1) {
//          _brightnessIdx = 0;
//      }
//
//
//      g_brightness = _aBrightness[_brightnessIdx];
//
//      break;

    case BUTTONMODE_COLOR:
        _colorIdx = up ? _colorIdx + 1: _colorIdx - 1;
        if (_colorIdx == COLOR_COUNT) {
            _colorIdx = COLOR_COUNT - 1;
        }
        if (_colorIdx == -1) {
            _colorIdx = 0;
        }
        g_settings.color = GetColorFromIdx(_colorIdx);
        AlsFill(0,0,0);
        F5x7WriteChar(1,0,'K', RGB_FROM_SETTING);
        F5x7WriteChar(1,6,'L', RGB_FROM_SETTING);
        AlsRefresh(ALSEFFECT_NONE);
        SleepNI(1000);
        break;

    case BUTTONMODE_BRIGHTNESS:
        g_settings.brightnessOffset = up ? g_settings.brightnessOffset + 1: g_settings.brightnessOffset - 1;
        if (g_settings.brightnessOffset > MAX_BRIGHTNESS_OFFSET) {
            g_settings.brightnessOffset = MAX_BRIGHTNESS_OFFSET;
        }
        if (g_settings.brightnessOffset == -1) {
            g_settings.brightnessOffset = 0;
        }
        AlsFill(0,0,0);
        F5x7WriteChar(1,4,0x30 + g_settings.brightnessOffset, g_brightness, g_brightness, g_brightness);
        AlsRefresh(ALSEFFECT_NONE);
        SleepNI(1000);
        break;

    case BUTTONMODE_RED:
        g_settings.color.r = up ? g_settings.color.r + 10 : g_settings.color.r - 10;
        break;

    case BUTTONMODE_GREEN:
        g_settings.color.g = up ? g_settings.color.g + 10 : g_settings.color.g - 10;
        break;

    case BUTTONMODE_BLUE:
        g_settings.color.b = up ? g_settings.color.b + 10 : g_settings.color.b - 10;
        break;
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

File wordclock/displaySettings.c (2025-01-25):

/*
 * displaySettings.c
 *
 *  Created on: Oct 7, 2016
 *      Author: rutger.huijgen
 */

#include <stdio.h> // printf
#include <stdint.h>
#include <string.h>
#include <time.h>
#include <sys/types.h>

#include "FreeRTOS.h"
#include "task.h"

#include "espressif/esp_common.h"
#include <espressif/esp_wifi.h>
#include "esp/uart.h" // uart_set_baud
#include "ws2812_i2s/ws2812_i2s.h"
#include "displaySettings.h"
#include "esp_glue.h"
#include <ldr.h>
#include <AddressableLedStrip.h>
#include <clock_words.h>
#include <font.h>
#include "settings.h"
#include "rgb2.h"

TPixel _frameCopy[WORDCLOCK_ROWS_MAX * WORDCLOCK_COLLS_MAX];
uint16_t _aLdrLevels[] = {808, 800, 700, 550, 300, 100, 50, 30, 10, 5};
static bool g_inNightMode = false;

TColor _definedColors[] = {
{255,255,255},    
{185,150,255},        
{128,000,255},    
{255,000,255},    
{255,000,128},
{255,000,000},
{255,128,000},    
{255,255,000},    
{128,255,000},        
{000,255,000},
{000,255,128},        
{000,255,255},
{000,128,255},        
{000,000,255}};

TColor GetColorFromIdx(TColorIdx idx)
{
    return _definedColors[idx];
}

bool DisplayInNightMode(void)
{
    return g_inNightMode;
}

/**
 * @return TRUE if brighness changed, else false
 */
bool SetBrightness(void)
{
    uint32_t i = 0;
    static uint8_t br = 100;
    bool res = FALSE;
    static uint32_t lastMeasurementTicks = 0;

    if (GetTicksDiffMs(lastMeasurementTicks, xTaskGetTickCount()) > 1000) {
        uint16_t v;
        LdrGetValue16(&v);

        while ((i < BRIGHTNESS_COUNT) && (v < _aLdrLevels[i])) {
            i++;
        }
        // When the lowest level light is measured, dimm the leds to the max, else use brightness setting.
        if (i == 0){
            g_inNightMode = TRUE;
        } else {
            i+= g_settings.brightnessOffset;
            g_inNightMode = FALSE;

        }

        if (i >= BRIGHTNESS_COUNT) {
            i = BRIGHTNESS_COUNT - 1;
        }
        if (v >= _aLdrLevels[i]) {
            br = g_settings.aBrightness[i];
        } else {
            br = 220; // Maximum brightness
        }
        //printf("LDR: %d, br: %d %d\n", v, br, g_brightness);
        lastMeasurementTicks = xTaskGetTickCount();
    }

    if (br > g_brightness){
        g_brightness += 1;
        if (br - g_brightness > 10) {
            g_brightness += 3;
        }
        res = TRUE;
    } else if (br < g_brightness) {
        g_brightness -= 1;
        if (g_brightness - br > 10) {
            g_brightness -= 3;
        }
        res = TRUE;
    }
    return res;
}

uint8_t ApplyBrightness(uint8_t color)
{
    uint32_t t;
    t = color * g_brightness;
    return (uint8_t)(t / 255);

}
uint8_t ApplyBgBrightness(uint8_t color)
{
    // If backgrondcolor white, then turn led off.
    if (g_settings.bgColor.r == 0 &&
        g_settings.bgColor.g == 0 &&
        g_settings.bgColor.b == 0) return 0;
    if (g_settings.bgColor.r == 255 &&
        g_settings.bgColor.g == 255 &&
        g_settings.bgColor.b == 255) return 0;
    uint32_t t;
    t = color * g_brightness;
    return (uint8_t)(t / 255);
}

static void WS2812_I2S_WriteData(TPixel* pixels, uint32_t nrOfPixels){  
    if (g_hw_settings.pixelType == PIXEL_TYPE_RGB) {
        ws2812_i2s_update((ws2812_pixel_t*) pixels, PIXEL_RGB);
    } else {
        // For the RGBW leds the white LED is used to show common value,
        // The calculated RGBW value should not be stored in the frame, therefor make a copy
        for (int i = 0; i < nrOfPixels; i++) {
            rgb2rgbw(_frameCopy[i], pixels[i], g_hw_settings.pixelType);
        }
        ws2812_i2s_update((ws2812_pixel_t*) _frameCopy, PIXEL_RGBW);
    }
}

void wordClockDisplay_init(void)
{
    //Set the brightness on boot
    g_brightness = 70;

    // Configure the GPIO
    gpio_enable(LEDSTRIP_GPIO_NR, GPIO_OUTPUT);

    printf("###ws2812##hardwareTyp is %d\n", g_hw_settings.hardwareType);
    if (g_hw_settings.hardwareType == HARDWARE_13_13 || g_hw_settings.hardwareType == HARDWARE_13_13_V2 || g_hw_settings.hardwareType == HARDWARE_13_13_V2_1 || g_hw_settings.hardwareType == HARDWARE_13_13_NOT_ACCURATE) {
        _displaySize[0] = 13;
        _displaySize[1] = 13;
    } else if (g_hw_settings.hardwareType == HARDWARE_11_11) {
        _displaySize[0] = 11;
        _displaySize[1] = 11;
    } else if (g_hw_settings.hardwareType == HARDWARE_9_8) {
        _displaySize[0] = 9;
        _displaySize[1] = 8;
    } else {
        _displaySize[0] = 11;
        _displaySize[1] = 11;
    }

    CWInit();
    if (g_hw_settings.pixelType == PIXEL_TYPE_RGB) {
        ws2812_i2s_init(_displaySize[0] *_displaySize[1], PIXEL_RGB);
    } else {
        ws2812_i2s_init(_displaySize[0] *_displaySize[1], PIXEL_RGBW);
    }
    AlsInit(_displaySize[0], _displaySize[1], WS2812_I2S_WriteData);

    FontInit(AlsSetLed);
}

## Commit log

2019-08-18 Included freecad tekening
    [wordclock_13x13_validatie.FCStd]
2019-08-18 saved a wordclock without squares
    [wordclock_13x13.FCStd]
2019-08-20 Freecad draw schotten
    [schotten.FCStd]
2019-09-05 split the code into modules, and made a 11X11 clock
    [schotten.FCStd, wordclock_13x13.FCStd, wordclock_13x13_validatie.FCStd]
2019-09-09 created own font, and some fixes for 11*11 clock
    [letterplaat_11x11.dxf]
2019-09-09 moved freecad folder
    [letterplaat_11x11.dxf, letterplaat_13x13.dxf]
2019-09-25 removed wrong DXF files and fix import
    [letterplaat_11x11.dxf, letterplaat_13x13.dxf]
2019-09-25 moved files
    [WOORDCLOCK.dxf, WOORDCLOCK_1.dxf, WOORDCLOCK_2.dxf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]
2019-11-20 update hardware
    [led_divider_11_11_frameless.stl, led_divider_13_13_Frameless.stl, letterplaat_13_13.FCStd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]
2019-11-25 uploaded letterplate 11x11 and made env.sh system independed
    [letterplate_11_11_ikea.stl]
2019-11-26 letterplaten en gatenboards
    [gatenboard.dxf, gatenboard_groot_13x13_half.dxf, gatenboard_groot_13x13_kwart.dxf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]
2019-11-26 verplaats gatenboard
    [gatenboard.dxf, gatenboard_groot_13x13_half.dxf, gatenboard_groot_13x13_kwart.dxf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]
2019-12-30 updated hardware drawings
    [gatenboard.dxf, gatenboard_groot_13x13_half.dxf, gatenboard_groot_13x13_kwart.dxf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]
2019-12-30 Show the current settings in the webpage
2020-01-05 made the new esp_open_rtos build (still a bug in the ledstrip driver)
    [buttons.c, displaySettings.c, esp_glue.c]
2020-01-24 apply rainbow filter before hierbenik position to make it more visible
2020-02-02 reduce debug print outout
2020-02-15 Upload last generated version of letterplaats G-code
    [letterplate_11_11.step]
2020-02-22 Updated the 11x11 and 13x13 letterplate for RHU, liberation is smoother now, removed unneded points in font to create nice arc
    [letterplate_11_11.FCStd, letterplate_11_11_V2.step, letterplate_13_13 v2.stl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]
2020-04-07 add the new drawings RHU
    [letterplate_13_13_fusion360_V3.dxf]
2020-04-20 Fixed assert in OS, and lower the wordclock main so AP mode has more time
    [esp_glue.c]
2020-04-20 revert prio change will fix in a other branch
    [esp_glue.c]
2020-04-20 Cleanup hardware drawing RHU
    [ledschotten_frameless_11_11 v29.stl, ledschotten_frameless_13_13 v14.stl, ledschotten_frameless_13_13 v16.stl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]
2020-04-23 Added fixed hardware drawing
    [letterplate_11_11_fusion360_v2.dxf, letterplate_13_13_fusion360_V4.dxf]
2020-05-11 Initial impl for sysparam fix
    [esp_glue.c]
2020-05-12 Moved the connection check in a task so the esp framework finishs its init before starting in ap mode
2020-07-10 None functional only hardware en readme changes
    [letterplate_11_11_freecad.dxf, letterplate_11_11_fusion360.dxf, letterplate_11_11_fusion360_v2.dxf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]
2020-09-06 add letterplate_13_13
    [letterplate_13_13_freecad.dxf]
2020-09-12 Fix hangup in http server when client is not properly closing socket
2020-11-20 drawing 120x120 housing
2020-11-22 120 housing update
2021-02-28 fix button handling
2021-12-18 added debug webpage for LDR and way to use rgbw ledstrip without the white led
2021-12-18 First version of PCB
    [Ledstrips_PCB.kicad_pcb, Ledstrips_PCB.sch]
2022-02-02 Fixed fire animation for 13x13 clock
    [displaySettings.c]
2022-02-02 renamed folder
    [Ledstrips_PCB.kicad_pcb, Ledstrips_PCB.sch]
2022-02-09 Initial change
    [Ledstrips_PCB.kicad_sch, Ledstrips_PCB.sch]
2022-02-16 13x13 letterplate V2
    [letterplate_13_13_V2_freecad.FCStd, letterplate_13_13_V2_freecad.dxf, letterplate_13_13_V2_freecad.step]
2022-02-16 Added Qcad converted file
    [letterplate_13_13_V2_Qcad.dxf]
2022-02-23 PCB in between commit
    [Ledstrips_PCB.kicad_sch]
2022-03-20 don't store the white value in the frame buffer
2022-05-04 Added extra SNTP servers through sntp.h (see submodule), fixed core lock, refactord wificfg
    [esp_glue.c]
2022-06-22 Updated PCB and ledschotten
    [Ledstrips_PCB.kicad_pcb, Ledstrips_PCB.kicad_sch, ledschotten_13_13_V2.dxf]
2022-11-27 update PCB and ngc files for 13x13 clock
    [Ledstrips_PCB.kicad_pcb, ledschotten_13_13_V2.dxf]
2022-11-28 Finisched PCB
    [Ledstrips_PCB.kicad_pcb, Ledstrips_PCB.kicad_sch]
2022-11-28 Added project for 11x11
    [backpannel_pcb_11x11_small.kicad_pcb, backpannel_pcb_11x11_small.kicad_sch, backpannel_pcb_13x13_big.kicad_pcb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]
2022-11-30 placement 11x11
    [backpannel_pcb_11x11_small.kicad_pcb, backpannel_pcb_11x11_small.kicad_sch]
2023-01-22 finished hardware for small and big clock
    [backpannel_pcb_11x11_small-B_Cu.gbl, backpannel_pcb_11x11_small-B_Mask.gbs, backpannel_pcb_11x11_small-B_Silkscreen.gbo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]
2023-10-06 Added all kinds of nieuw hardware
    [aanvoersnelheid_berekenen.xlsx, backpannel_pcb_11x11_small.step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]
2023-10-08 Fix stupit way of printing and wrong substraction
2023-11-06 increase do_flash uart speed
2024-07-01 only NC files
    [letterplate_13_13_V2_freecad.FCStd]
2024-10-27 Added sleep in case of invalid recv
2024-10-27 Added sleep in case realtime-udp failes
